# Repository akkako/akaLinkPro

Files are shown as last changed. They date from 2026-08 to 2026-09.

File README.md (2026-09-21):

# akaLinkPro

akaLinkPro 是一个基于 HPM5300 的高性能 CMSIS-DAP 调试器。

- 主固件：`firmware/application_5301`
- DFU/MSC Bootloader：`firmware/bootloader_dfu`
- 配置上位机（WebHID）：`docs/index.html`

构建 / 烧录 / 调试说明见 `.opencode/skills/akalinkpro-firmware/SKILL.md`。

## License

本项目采用 **Apache License 2.0** 许可，详见根目录 [`LICENSE`](LICENSE)。

```
Copyright (c) 2026 akaInstruments

Licensed under the Apache License, Version 2.0 (the "License");
you may not use this file except in compliance with the License.
You may obtain a copy of the License at

    http://www.apache.org/licenses/LICENSE-2.0
```

## 第三方组件

本项目在源码与构建中使用/参考了以下第三方组件，其版权归各自作者所有，
并按其各自的许可证分发（这些组件的原始许可证声明请见对应文件/目录）：

| 组件 | 用途 | 许可证 |
| --- | --- | --- |
| [HPMicro HPM SDK](https://github.com/hpmicro/hpm_sdk) | HPM5301 SoC/驱动/启动/链接脚本 | BSD-3-Clause |
| [ARM CMSIS-DAP](https://github.com/ARM-software/CMSIS-DAP) | CMSIS-DAP 命令引擎（`src/dap/`） | Apache-2.0 |
| [CherryUSB](https://github.com/cherry-embedded/CherryUSB) | USB 设备协议栈 | Apache-2.0 |
| [CherryRB](https://github.com/cherry-embedded/CherryRB) | 无锁环形缓冲区 | Apache-2.0 |
| [EasyFlash](https://github.com/armink/EasyFlash) | 参数持久化（`src/easyflash/`） | MIT |

> 若再分发二进制，请一并保留上述组件的版权与许可证声明。

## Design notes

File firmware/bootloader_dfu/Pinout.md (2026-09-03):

# akaLink Pro Pinout define

| Pin name | IO name | alt function | description | Init state |
| --- | --- | --- | --- | --- |
| ISP_TX | PA00 | UART0.TXD | ISP and debug print serial port | |
| ISP_RX | PA01 | UART0.RXD | ISP and debug print serial port | |
| BOOT0 | PA02 | None | Strapping pin | |
| BOOT1 | PA03 | None | Strapping pin | |
| DBG_JTDO | PA04 | JTAG | Debug port | |
| DBG_JTDI | PA05 | JTAG | Debug port | |
| DBG_JTCK | PA06 | JTAG | Debug port | |
| DBG_JTMS | PA07 | JTAG | Debug port | |
| JTDI_TXD | PA08 | UART2.TXD | VCOM port | |
| JTDO_RXD | PA09 | UART2.RXD | VCOM port | |
| DFU_PIN  | PA10 | GPIO0 Input | DFU mode entry detect | Pull-down GPIO0 Input |
| USB_D+ | PA24 | USB | USB communication pin | |
| USB_D- | PA25 | USB | USB communication pin | |
| nRESET | PA26 | GPIO0 Output | | GPIO0 Output Low |
| JTCK | PA27 | FGPIO Output | | |
| JTMS_IN  | PA28 | FGPIO Input  | | |
| JTMS_OUT | PA29 | FGPIO Output | | |
| JTMS_DIR | PA30 | FGPIO Output | | |
| JTRST | PA31 | GPIO0 Output | | |
| SEL0 | PB08 | GPIO0 Input | Device hardware type detect | Pull-up GPIO0 Input |
| SEL1 | PB09 | GPIO0 Input | Device hardware type detect | Pull-up GPIO0 Input |
| ADC_VREF | PB10 | ADC0.IN2 | External Vref detect | |
| LED1 | PB11 | GPIO0 Output | | GPIO0 Output Low |
| LED2 | PB12 | GPIO0 Output | | GPIO0 Output Low |
| 5V_EN | PB13 | GPIO0 Output | | GPIO0 Output Low |
| AUX_RXD  | PB14 | UART3.RXD | Auxiliary COM port | |
| AUX_TXD  | PB15 | UART3.TXD | Auxiliary COM port | |
| Unused | PY00 | None | | GPIO0 Output Low |
| Unused | PY01 | None | | GPIO0 Output Low |

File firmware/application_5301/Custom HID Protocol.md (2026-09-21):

# Custom HID 通信协议

## HID 数据包

固定长度64字节

Byte[0x00] = Report ID
Byte[0x01] = Data Length（包括 Command type 和后面的数据长度）
Byte[0x02] = Command type
Byte[0x03-0x3F] = Command data（可选）

- 主机下发 request 使用 Report ID 0x01，设备回应 response 使用 Report ID 0x02。
- Data Length = Command type 字节数(1) + 后续有效数据字节数。

## 指令类型

1. 获取配置指令 0x01
   主机发送 request
   Byte[0x00] = 0x01 // Report ID
   Byte[0x01] = 0x01 // Data Length
   Byte[0x02] = 0x01 // Command type
   设备回应 response
   Byte[0x00] = 0x02 // Report ID
   Byte[0x01] = 0x07 // Data Length
   Byte[0x02] = 0x01 // Command type
   Byte[0x03] = 输出模式 0x00 - SWD + VCOM; 0x01 - SWD + JTAG
   Byte[0x04] = 5V输出模式 0x00 - Disable; 0x01 - Enable
   Byte[0x05] = 时钟加速模式 0x00 - Disable; 0x01 - Enable
   Byte[0x06] = LED1 显示模式 0x01 - 0x09（见配置说明）
   Byte[0x07] = LED2 显示模式 0x01 - 0x09（见配置说明）
   Byte[0x08] = 外部参考设定值 低八位（单位 mV）
   Byte[0x09] = 外部参考设定值 高八位（单位 mV，范围 1800 - 5000）
   设备回应代表成功

2. 设置配置指令 0x02
   主机发送 request
   Byte[0x00] = 0x01 // Report ID
   Byte[0x01] = 0x07 // Data Length
   Byte[0x02] = 0x02 // Command type
   Byte[0x03] = 输出模式 0x00 - SWD + VCOM; 0x01 - SWD + JTAG
   Byte[0x04] = 5V输出模式 0x00 - Disable; 0x01 - Enable
   Byte[0x05] = 时钟加速模式 0x00 - Disable; 0x01 - Enable
   Byte[0x06] = LED1 显示模式 0x01 - 0x09
   Byte[0x07] = LED2 显示模式 0x01 - 0x09
   Byte[0x08] = 外部参考设定值 低八位（单位 mV）
   Byte[0x09] = 外部参考设定值 高八位（单位 mV，范围 1800 - 5000）
   设备回应 response
   Byte[0x00] = 0x02 // Report ID
   Byte[0x01] = 0x01 // Data Length
   Byte[0x02] = 0x02 // Command type
   设备回应代表成功
   说明：本指令只写入内存并立即生效，掉电不保存；需要掉电保存请随后发送保存配置指令 0x04。
   越界的 LED 模式会被钳制为 0x09（常灭），越界的外部参考设定值会被钳制到 1800 - 5000。

3. 获取 Target 电压获取指令 0x03
   主机发送 request
   Byte[0x00] = 0x01 // Report ID
   Byte[0x01] = 0x01 // Data Length
   Byte[0x02] = 0x03 // Command type
   设备回应 response
   Byte[0x00] = 0x02 // Report ID
   Byte[0x01] = 0x03 // Data Length
   Byte[0x02] = 0x03 // Command type
   Byte[0x03] = 电压数据低八位
   Byte[0x04] = 电压数据高八位（电压单位为mV）
   设备回应代表成功
   说明：返回 PB10 分压点经 x2 还原后的外部参考电压（ADC 量程 3.3V）。

4. 保存当前配置设置指令 0x04
   主机发送 request
   Byte[0x00] = 0x01 // Report ID
   Byte[0x01] = 0x01 // Data Length
   Byte[0x02] = 0x04 // Command type
   设备回应 response
   Byte[0x00] = 0x02 // Report ID
   Byte[0x01] = 0x01 // Data Length
   Byte[0x02] = 0x04 // Command type
   设备回应代表成功
   说明：将当前配置写入 flash 持久化保存，见“配置持久化”章节。

5. 获取型号指令 0x10
   主机发送 request
   Byte[0x00] = 0x01 // Report ID
   Byte[0x01] = 0x01 // Data Length
   Byte[0x02] = 0x10 // Command type
   设备回应 response
   Byte[0x00] = 0x02 // Report ID
   Byte[0x01] = 0x13 // Data Length
   Byte[0x02] = 0x10 // Command type
   Byte[0x03] = 'a'
   Byte[0x04] = 'k'
   Byte[0x05] = 'a'
   Byte[0x06] = 'L'
   Byte[0x07] = 'i'
   Byte[0x08] = 'n'
   Byte[0x09] = 'k'
   Byte[0x0A] = ' '
   Byte[0x0B] = 'C'
   Byte[0x0C] = 'M'
   Byte[0x0D] = 'S'
   Byte[0x0E] = 'I'
   Byte[0x0F] = 'S'
   Byte[0x10] = '-'
   Byte[0x11] = 'D'
   Byte[0x12] = 'A'
   Byte[0x13] = 'P'
   Byte[0x14] = \0
   设备回应代表成功

6. 获取序列号指令 0x11
   主机发送 request
   Byte[0x00] = 0x01 // Report ID
   Byte[0x01] = 0x01 // Data Length
   Byte[0x02] = 0x11 // Command type
   设备回应 response
   Byte[0x00] = 0x02 // Report ID
   Byte[0x01] = 0x0E // Data Length
   Byte[0x02] = 0x11 // Command type
   Byte[0x03] = SN 第 1 位 ACSII
   Byte[0x04] = SN 第 2 位 ACSII
   Byte[0x05] = SN 第 3 位 ACSII
   Byte[0x06] = SN 第 4 位 ACSII
   Byte[0x07] = SN 第 5 位 ACSII
   Byte[0x08] = SN 第 6 位 ACSII
   Byte[0x09] = SN 第 7 位 ACSII
   Byte[0x0A] = SN 第 8 位 ACSII
   Byte[0x0B] = SN 第 9 位 ACSII
   Byte[0x0C] = SN 第 10 位 ACSII
   Byte[0x0D] = SN 第 11 位 ACSII
   Byte[0x0E] = SN 第 12 位 ACSII
   Byte[0x0F] = \0
   设备回应代表成功

7. 获取硬件版本号 0x12
   主机发送 request
   Byte[0x00] = 0x01 // Report ID
   Byte[0x01] = 0x01 // Data Length
   Byte[0x02] = 0x12 // Command type
   设备回应 response
   Byte[0x00] = 0x02 // Report ID
   Byte[0x01] = 0x06 // Data Length
   Byte[0x02] = 0x12 // Command type
   Byte[0x03] = HW 第 1 位 ACSII
   Byte[0x04] = HW 第 2 位 ACSII
   Byte[0x05] = HW 第 3 位 ACSII
   Byte[0x06] = HW 第 4 位 ACSII
   Byte[0x07] = \0
   设备回应代表成功

8. 获取固件版本号 0x13
   主机发送 request
   Byte[0x00] = 0x01 // Report ID
   Byte[0x01] = 0x01 // Data Length
   Byte[0x02] = 0x13 // Command type
   设备回应 response
   Byte[0x00] = 0x02 // Report ID
   Byte[0x01] = 0x06 // Data Length
   Byte[0x02] = 0x13 // Command type
   Byte[0x03] = FW 第 1 位 ACSII
   Byte[0x04] = FW 第 2 位 ACSII
   Byte[0x05] = FW 第 3 位 ACSII
   Byte[0x06] = FW 第 4 位 ACSII
   Byte[0x07] = \0
   设备回应代表成功

9. 获取Bootloader版本号 0x14
   主机发送 request
   Byte[0x00] = 0x01 // Report ID
   Byte[0x01] = 0x01 // Data Length
   Byte[0x02] = 0x14 // Command type
   设备回应 response
   Byte[0x00] = 0x02 // Report ID
   Byte[0x01] = 0x06 // Data Length
   Byte[0x02] = 0x14 // Command type
   Byte[0x03] = BL 第 1 位 ACSII
   Byte[0x04] = BL 第 2 位 ACSII
   Byte[0x05] = BL 第 3 位 ACSII
   Byte[0x06] = BL 第 4 位 ACSII
   Byte[0x07] = \0
   设备回应代表成功

10. 获取硬件生产日期指令 0x15
   主机发送 request
   Byte[0x00] = 0x01 // Report ID
   Byte[0x01] = 0x01 // Data Length
   Byte[0x02] = 0x15 // Command type
   设备回应 response
   Byte[0x00] = 0x02 // Report ID
   Byte[0x01] = 0x15 // Data Length
   Byte[0x02] = 0x15 // Command type
   Byte[0x03-0x15] = 日期字符串（19 字节，如 "2026-08-06"）
   Byte[0x16] = \0
   设备回应代表成功

11. 获取固件编译日期指令 0x16
   主机发送 request
   Byte[0x00] = 0x01 // Report ID
   Byte[0x01] = 0x01 // Data Length
   Byte[0x02] = 0x16 // Command type
   设备回应 response
   Byte[0x00] = 0x02 // Report ID
   Byte[0x01] = 0x15 // Data Length
   Byte[0x02] = 0x16 // Command type
   Byte[0x03-0x15] = 日期字符串（19 字节）
   Byte[0x16] = \0
   设备回应代表成功

12. 获取Bootloader编译日期指令 0x17
   主机发送 request
   Byte[0x00] = 0x01 // Report ID
   Byte[0x01] = 0x01 // Data Length
   Byte[0x02] = 0x17 // Command type
   设备回应 response
   Byte[0x00] = 0x02 // Report ID
   Byte[0x01] = 0x15 // Data Length
   Byte[0x02] = 0x17 // Command type
   Byte[0x03-0x15] = 日期字符串（19 字节）
   Byte[0x16] = \0
   设备回应代表成功

13. 设备复位指令 0xFE
   主机发送 request
   Byte[0x00] = 0x01 // Report ID
   Byte[0x01] = 0x01 // Data Length
   Byte[0x02] = 0xFE // Command type
   设备复位，不会回复，此时连接断开

14. 进入DFU模式设置指令 0xFF
   主机发送 request
   Byte[0x00] = 0x01 // Report ID
   Byte[0x01] = 0x01 // Data Length
   Byte[0x02] = 0xFF // Command type
   设备复位进入DFU模式，不会回复，此时连接断开

## 配置说明

1. 输出模式
0x00 - SWD + VCOM 此时 JTAG 功能不可用，TDI 和 TDO 用于 UART
0x01 - SWD + JTAG 此时 VCOM 功能不可用，TDI 和 TDO 用于 JTAG

2. 5V输出模式
0x00 - 关闭 5V 对外输出
0x01 - 开启 5V 对外输出，可以用于为外接隔离器模块或目标板供电
注意：该引脚同时给板载电平转换供电，关闭后 JTAG/SWD 电平转换可能无法工作；出厂默认开启。

3. 时钟加速模式
0x00 - 关闭时钟加速模式，此时 DAP_SWJ_Clock 指令将按照设定频率向下取整设置 SWD 和 JTAG 输出频率，适用于 openocd 等上位机
0x01 - 开启时钟加速模式，此时 DAP_SWJ_Clock 指令将按照设定频率x10向下取整设置 SWD 和 JTAG 输出频率，适用于 Keil MDK 上位机

4. LED 显示模式（LED1 = PB11 蓝色，LED2 = PB12 黄色，高电平点亮）
可分别为两个 LED 配置 0x01 - 0x09 中任意一种模式，两个 LED 可相同也可不同：

0x01 - DAP RUNNING 状态：RUNNING=1 则亮，=0 则灭
0x02 - DAP CONNECT 状态：CONNECT=1 则亮，=0 则灭
0x03 - DAP 状态：RUNNING 与 CONNECT 任一为 1 则以 5Hz（200ms 周期，亮/灭各 100ms）闪烁，两者都为 0 则常亮
0x04 - 调试器电源状态：上电常亮
0x05 - 外部参考电源状态：ADC 检测到外部参考电压高于设定值的 90% 时点亮，低于 85% 时熄灭（5% 滞回）
0x06 - CDC 串口 TX 状态（调试器 UART 向外发数据）：有数据发送时点亮，最低点亮 50ms，持续发送则常亮
0x07 - CDC 串口 RX 状态（调试器 UART 接收数据）：有数据接收时点亮，最低点亮 50ms，持续接收则常亮
0x08 - CDC 串口 TX 或 RX 状态：TX 或 RX 任一触发，逻辑同上
0x09 - 常灭

出厂默认：LED1 = 0x04，LED2 = 0x05。

5. 外部参考电压设定值（单位 mV，范围 1800 - 5000）
用于 LED 显示模式 0x05 的判定阈值，对应经 x2 还原后的外部参考电压。出厂默认 3300mV。

## 配置持久化

- 设置配置指令（0x02）只修改内存中的配置并立即生效，掉电丢失。
- 保存配置指令（0x04）通过 **EasyFlash（ENV, NG 模式）** 写入 QSPI NOR flash，
  具备磨损平衡与掉电保护。
- 存储位置：APP 固件区尾部保留的两个 4K 扇区（`0x800FE000` 与 `0x800FF000`），
  不占用 Bootloader 区（`0x80000000` - `0x8001FFFF`）。
- ENV key 为 `"cfg"`，value 为整个 `api_param_t`；上电自动加载，校验失败则写回出厂默认。
- 常规 APP 升级（J-Link 或 dfu-util）不会覆盖该区域。
- 详见 `Flash_Memory_Map.md` 与 `Firmware_Integrity_Plan.md`。

## 固件元数据（版本 / CRC）

- 版本、编译时间、描述、硬件版本等由构建后 `firmware/tools/pack.py` 注入：
  - **APP**：`0x80020000` 起 256 B 头（签名 + 长度 + CRC32 + 版本 + 编译时间 + 描述），代码入口 `0x80020100`；
  - **Bootloader**：`0x8001F000` 起 256 B 信息块（版本 + 编译时间 + 硬件版本 + 生产日期）。
- 版本单一来源：`firmware/version.json`；编译时间取打包时刻。
- Bootloader 启动时校验 APP 头（签名 + 长度 + CRC32），失败则停留在 DFU 模式。
- 指令 `0x12`–`0x17` 即从上述固定地址读取返回。

## WebUI 配置界面

点击连接按钮尝试连接 HID 设备
弹出 HID 设备选择框，选择 akaLink CMSIS-DAP 设备
进行连接，如果连接失败显示错误提示信息
连接成功，读取型号，序列号，配置信息，并将数据显示在页面上
此时可以修改配置，修改完配置不立即写入
点击保存配置按钮，将配置写入并保存
点击复位按钮，进行复位操作
点击进入DFU模式按钮，进入DFU模式

需要实时监测 HID 设备的连接状态，如果丢失连接要及时响应，清除显示的数据
在未连接状态下，只有连接按钮可用，其他按钮不可用，配置项目不可选

每个配置项和按键，当鼠标指上去的时候需要有提示信息

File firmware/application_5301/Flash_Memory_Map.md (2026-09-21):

# akaLink Pro Flash 存储区分布

适用芯片：**HPM5301**，外挂 **1 MB QSPI NOR**，XIP 基址 `0x80000000`。
NOR 扇区（sector）大小：**4 KB (0x1000)**，共 256 个扇区（扇区号 0 – 255）。

> 所有地址均为 CPU 视角的 flash 映射地址（XIP）。写入/擦除通过 ROM API
> (`rom_xpi_nor_*`) 完成，偏移量为「映射地址 − 0x80000000」。

## 1. 总体分布

| 区域 | 起始地址 | 结束地址 | 大小 | 扇区号 | 说明 |
| --- | --- | --- | --- | --- | --- |
| Bootloader 代码 | `0x80000000` | `0x8001EFFF` | < 124 KB | 0 – 30 | DFU 引导程序（实际 ~40 KB） |
| Bootloader 信息块 | `0x8001F000` | `0x8001F0FF` | 256 B | 31 | 版本/编译时间/硬件版本/生产日期 |
| APP 头 | `0x80020000` | `0x800200FF` | 256 B | 32 | DFU 签名 + 长度 + CRC32 + 版本/时间/描述 |
| APP 代码 | `0x80020100` | `0x800FDFFF` | ~895 KB | 32 – 253 | 应用程序链接区，入口 `0x80020100` |
| EasyFlash ENV 区 | `0x800FE000` | `0x800FFFFF` | 8 KB | 254 – 255 | 配置持久化（见 §4） |

- APP 头首 4 字节为 DFU 签名 `0x48504D21`（"HPM!"），代码入口 `0x80020100`。
- Bootloader 校验通过后跳转到 `0x80020100`。
- 元数据由构建后 `firmware/tools/pack.py` 注入，详见 §3.2 / §4.5。

## 2. Bootloader 区（`0x80000000` – `0x8001FFFF`）

| 地址 | 内容 | 说明 |
| --- | --- | --- |
| `0x80000400` | `nor_cfg_option` | QSPI NOR 配置字（Rom 引导用） |
| `0x80001000` | `boot_header` | HPM 启动头 |
| `0x80003000` | `.start` / 代码 | Bootloader 可执行代码 |
| `0x8001FFFC` | 保留 | 区尾，下一个区域为 APP |

## 3. APP 固件区（`0x80020000` – `0x800FDFFF`）

| 地址 | 内容 | 说明 |
| --- | --- | --- |
| `0x80020000`–`0x800200FF` | **APP 头** | 见 §3.1；由 `pack.py` 注入 |
| `0x80020100` | 代码入口 `_start` | 实际占用约 80 KB（随版本变化） |
| 区尾 `0x800FDFFF` | APP 区上界（含） | 其后为 8 KB EasyFlash 区 |

APP 区使用**自定义链接脚本** `linker/flash_dfu_app.ld`（经 `CUSTOM_GCC_LINKER_FILE` 指定），
在 `.dfu_signature` 之后 `. = ALIGN(0x100)` 预留 APP 头，使入口落到 `0x80020100`。
区大小仍为 `APP_LENGTH = _flash_size − _dfu_bl_length = 0xFE000 − 0x20000 = 0xDE000`。

### 3.1 APP 头结构（256 B @ `0x80020000`）

| 偏移 | 长度 | 字段 | 来源 |
| --- | --- | --- | --- |
| `0x00` | 4 | DFU 签名 `0x48504D21` | 链接器（保持） |
| `0x04` | 4 | 代码长度 `app_code_len` | `pack.py` |
| `0x08` | 4 | 代码 CRC32（种子 `0x0D000721`） | `pack.py` |
| `0x0C` | 4 | 头格式版本 = 1 | `pack.py` |
| `0x10` | 8 | 固件版本串 | `version.json: app_fw_ver` |
| `0x18` | 20 | 固件编译时间 `YYYY/MM/DD HH:MM:SS` | 打包时刻 |
| `0x2C` | 24 | 固件描述 | `version.json: app_desc` |
| `0x44` | 0xBC | 保留 | — |

## 3.2 Bootloader 信息块（256 B @ `0x8001F000`）

| 偏移 | 长度 | 字段 | 来源 |
| --- | --- | --- | --- |
| `0x00` | 4 | magic `"BLI1"` (`0x31494C42`) | `pack.py` |
| `0x04` | 4 | Bootloader 代码长度 | `pack.py` |
| `0x08` | 4 | Bootloader CRC32（预留，未校验） | — |
| `0x0C` | 4 | 格式版本 = 1 | `pack.py` |
| `0x10` | 8 | Bootloader 版本串 | `version.json: bl_ver` |
| `0x18` | 20 | Bootloader 编译时间 | 打包时刻 |
| `0x2C` | 8 | 硬件版本串 | `version.json: hw_ver` |
| `0x34` | 20 | 硬件生产日期 | `version.json: hw_prod_date` |

### 3.3 版本信息源

统一配置于 `firmware/version.json`（`app_fw_ver` / `app_desc` / `bl_ver` / `hw_ver` / `hw_prod_date`），
由 app 与 bootloader 的 `pack.py`（`firmware/tools/pack.py`）在构建后写入；编译时间取打包时刻。

## 4. 参数存储区（`0x800FE000` – `0x800FFFFF`，EasyFlash）

由 **EasyFlash（ENV, NG 模式）** 管理的持久化区，占用 2 个 4 KB 扇区（8 KB），
自带磨损平衡与掉电保护，不再使用早期的双槽 ping-pong 自定义格式。

| 区域 | 地址范围 | 扇区号 | 大小 | 说明 |
| --- | --- | --- | --- | --- |
| EasyFlash ENV 区 | `0x800FE000` – `0x800FFFFF` | 254 – 255 | 8 KB | `ENV_AREA_SIZE`，`EF_START_ADDR` |

- 逻辑：ENV key `"cfg"` 保存整个 `api_param_t` blob（`ef_get_env_blob`/`ef_set_env_blob`）。
- 物理：每个扇区头 magic `EF40`；每个 ENV 节点头 magic `KV40` + 长度 + CRC32 + 状态位；
  2 个扇区间自动 GC / 磨损平衡，一个扇区通常留作 GC 空扇区。
- 出厂默认：由 `api_param.c` 的 `g_param_default` 提供（`ef_port.c` 的 `default_env_set`），
  首次上电 / 扇区无效 / `EF_ENV_VER_NUM` 变化时写入。
  默认值：`output_mode=0, usb5v=1, clock_accel=0, led1=4, led2=5, vref=3300`。

分层实现：

| 层 | 文件 | 职责 |
| --- | --- | --- |
| 硬件驱动 (`drv`) | `src/drv/drv_flash.c/.h` | 封装 ROM API：`drv_flash_init/read/erase/write`，处理字节对齐与 Cache |
| 存储库端口 | `src/easyflash/port/ef_port.c` | 把 EasyFlash 的 `ef_port_read/erase/write/env_lock` 及默认 ENV 接到 `drv_flash` |
| 存储库 | `src/easyflash/src/*` | EasyFlash 本体（ENV/GC/CRC） |
| 应用 | `src/api/api_param.c` | 通过 `ef_get_env_blob`/`ef_set_env_blob("cfg")` 存取配置 |

> 驱动/存储库不感知业务字段，应用层只面对 key/value，换存储介质只需改 `drv` 层。

## 5. 相关代码 / 链接约束（改尾部保留区时必须同步）

| 位置 | 约束 | 当前值 |
| --- | --- | --- |
| `application_5301/CMakeLists.txt` | APP 链接 `_flash_size`（决定 APP 区上界） | `0xFE000`（= 1 MB − 8 KB） |
| `application_5301/CMakeLists.txt` | Bootloader 预留 `_dfu_bl_length` | `0x20000` |
| `application_5301/CMakeLists.txt` | APP 自定义链接脚本 `CUSTOM_GCC_LINKER_FILE` | `linker/flash_dfu_app.ld` |
| `application_5301/CMakeLists.txt` | APP POST_BUILD 打包（写入 APP 头） | `tools/pack.py app` |
| `bootloader_dfu/CMakeLists.txt` | Bootloader POST_BUILD 打包（写入信息块） | `tools/pack.py boot` |
| `firmware/version.json` | 版本/描述/硬件信息唯一来源 | 见 §3.3 |
| `application_5301/boards/akaLinkPro/board.h` | 尾部保留大小 `BOARD_PARAM_RESERVED_SIZE` | `0x2000`（8 KB） |
| `application_5301/src/easyflash/inc/ef_cfg.h` | `EF_START_ADDR` / `ENV_AREA_SIZE`（= 尾部保留区） | 由 `BOARD_*` 推出 |
| `bootloader_dfu/boards/akaLinkPro/board.h` | `BOARD_DFU_WRITABLE_SIZE` | `BOARD_FLASH_SIZE − 0x2000` |
| `bootloader_dfu/src/dfu_flash_port.c` | DFU 擦除/写入/读取上界 | `< 0x800FE000` |
| `bootloader_dfu/src/dfu_desc.c` | DfuSe 描述的可写区大小 | 扣除 8 KB |

EasyFlash ENV 区地址：
`EF_START_ADDR = 0x80000000 + BOARD_FLASH_SIZE − BOARD_PARAM_RESERVED_SIZE`
`ENV_AREA_SIZE = BOARD_PARAM_RESERVED_SIZE`（= 2 × `EF_ERASE_MIN_SIZE` = 2 × 4 KB）

## 6. 新增自定义数据区的方法

在 **flash 顶端**从 EasyFlash 区继续向下预留（保持 Bootloader 区不动），并同步缩小 APP 区。

### 6.1 示例：新增 2 个扇区（8 KB）自定义数据区

把 APP 区上界从 `0x800FE000` 下调到 `0x800FC000`，自定义区放 `0x800FC000` – `0x800FDFFF`。调整后布局：

| 区域 | 地址范围 | 扇区号 | 大小 |
| --- | --- | --- | --- |
| APP 固件 | `0x80020000` – `0x800FBFFF` | 32 – 251 | 880 KB |
| 自定义数据区（示例） | `0x800FC000` – `0x800FDFFF` | 252 – 253 | 8 KB |
| EasyFlash ENV 区 | `0x800FE000` – `0x800FFFFF` | 254 – 255 | 8 KB |

此时尾部总保留 `TAIL = 4 × 0x1000 = 0x4000`：APP `_flash_size = 0x100000 − 0x4000 = 0xFC000`。

### 6.2 修改清单（模板）

设新增数据区共 `K` 个扇区，尾部总保留 `TAIL = (2 + K) × 0x1000` 字节：

| 文件 | 修改 |
| --- | --- |
| `application_5301/CMakeLists.txt` | `_flash_size = 0x100000 − TAIL` |
| `application_5301/boards/akaLinkPro/board.h` | `BOARD_PARAM_RESERVED_SIZE` → 改用实际尾部总保留大小（或新增 `BOARD_TAIL_RESERVED_SIZE`） |
| `application_5301/src/easyflash/inc/ef_cfg.h` | `EF_START_ADDR`/`ENV_AREA_SIZE` 按新的 EasyFlash 区重算 |
| `bootloader_dfu/boards/akaLinkPro/board.h` | `BOARD_DFU_WRITABLE_SIZE = BOARD_FLASH_SIZE − TAIL` |
| `bootloader_dfu/src/dfu_flash_port.c` | 无需改（引用 `BOARD_DFU_WRITABLE_SIZE`），确保不越界 |
| `bootloader_dfu/src/dfu_desc.c` | DfuSe 描述扣除 `TAIL` |

自定义数据区建议（两种方式）：
- **使用 EasyFlash**：为每个数据区分配独立的 ENV key（如 `"factory"`、`"calib"`），
  由 EasyFlash 统一做 GC / 磨损平衡；地址只需在 `ef_cfg.h` 调整 ENV 区范围与 `default_env_set`。
- **裸 drv_flash**：直接调用 `drv_flash_read/erase/write(addr, buf, size)`（绝对地址，字节粒度），
  自行在区首放 `magic + version + CRC32`，写前先 `drv_flash_erase` 整个扇区。
- 每个独立数据区至少占 1 个 4 KB 扇区（擦除最小单位）。
- 地址计算：`区起始 = 0x80100000 − TAIL + 本区在尾部内的偏移`。

## 7. 快速校验命令（J-Link）

```
device HPM5301xEGx
si JTAG
jtagconf -1 -1
speed 4000
connect
mem8  0x80020000,64     // APP 头：21 4D 50 48 + len + CRC32 + "0.1" + 时间 + 描述
mem8  0x80020100,8      // APP 入口代码（_start）
mem8  0x8001F000,64     // Bootloader 信息块："BLI1" + "1.0" + 时间 + "A.0" + 生产日期
mem8  0x800FE000,16     // EasyFlash 扇区头，含 "EF40" (45 46 34 30)
mem8  0x800FE010,16     // ENV 节点头 "KV40" (4B 56 34 30) + key "cfg"
mem8  0x800FF000,16     // 第二个 ENV 扇区（GC 备用，通常为空）
exit
```

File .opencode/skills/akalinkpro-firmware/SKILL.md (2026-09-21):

---
name: akalinkpro-firmware
description: akaLinkPro (HPM5301 CMSIS-DAP) firmware build, flash and debug guide. Use when building, flashing (J-Link/JTAG or dfu-util), debugging (VSCode GDB / J-Link GDB Server), or editing files under firmware/application_5301 and firmware/bootloader_dfu in this repo.
---

# akaLinkPro 固件构建 / 烧录 / 调试

本仓库是 **HPM5301** 上的 CMSIS-DAP 调试器（akaLinkPro）。
- 主固件：`firmware/application_5301`（`akaLinkPro_App`）
- DFU Bootloader：`firmware/bootloader_dfu`（`akaLinkPro_Boot`）
- `firmware/application_5331` 是另一芯片变体，非本流程重点。

调试探针：**J-Link V11**，串口 `50120677`，**只能走 JTAG**。

---

## 0. 其他 skill 索引

除了阅读本 skill 外，还应该阅读以下skill：

```
	jlink/SKILL.md
```

## 1. 目录结构

```
firmware/
  version.json                      版本/描述/硬件信息唯一来源（pack 读取）
  tools/pack.py                     构建后注入 APP 头(长度/CRC32/版本/时间/描述) 与 BL 信息块
  application_5301/                 主固件 (CMSIS-DAP)
    CMakeLists.txt                  自定义链接脚本 linker/flash_dfu_app.ld；POST_BUILD 调用 pack.py
    linker/flash_dfu_app.ld         预留 256B APP 头，入口 0x80020100（CUSTOM_GCC_LINKER_FILE）
    build_dfu.bat                   构建到 ./build_dfu（不调用 dfu-util）
    program.bat                     对 build_dfu 产物执行 dfu-util 烧录（用 _pack.bin）
    flash_jlink.bat                 build_dfu + JLink 烧录 APP（用 _pack.hex）
    gdb_server.bat                  启动 JLinkGDBServerCL（VSCode 调试用）
    Flash_Memory_Map.md             Flash 布局（含元数据/ EasyFlash）
    Firmware_Integrity_Plan.md      完整性校验+版本嵌入方案与自检
    Custom HID Protocol.md          HID 协议（配置/元数据）
    boards/akaLinkPro/              board.c/h, clock.c/h, pinmux.c/h, akaLinkPro.yaml
    src/  main.c, usb/, dap/, api/, led/, drv/, easyflash/, dfu/
  bootloader_dfu/                   DFU Bootloader
    CMakeLists.txt                  链接 flash_xip.ld，128K flash；POST_BUILD 调用 pack.py
    build.bat / build_xip.bat       ./build / ./build_xip（JLink 流程）
    flash_jlink.bat                 build_xip + JLink 烧录 bootloader（用 _pack.hex）
    src/  main.c, dfu_desc.c, hpm_dfu_trigger.c, boot_port_board_hpm.c, dfu_flash_port.c,
          vfat.c/.h（虚拟 FAT16 U 盘）, msc_if.c（MSC 回调）
    Bootloader_USB_Upgrade_Plan.md  U 盘升级方案
```

构建产物目录 `build` / `build_xip` / `build_dfu` 均已在 `.gitignore` 中忽略。
每次构建后生成 **打包镜像** `*_pack.hex` / `*_pack.bin`（含元数据），烧录请用打包镜像。

---

## 2. 内存布局与关键地址

HPM5301，外挂 1MB QSPI NOR，XIP 基址 `0x80000000`。

| 区域 | 地址 | 链接脚本 | 说明 |
| --- | --- | --- | --- |
| Bootloader 代码 | `0x80000000 - 0x8001EFFF` | `flash_xip.ld` | 含 `nor_cfg_option`@0x400、`boot_header`@0x1000、`.start`@0x3000 |
| Bootloader 信息块 | `0x8001F000 - 0x8001F0FF` (256B) | — | `pack.py` 写入：BL 版本/编译时间/硬件版本/生产日期 |
| APP 头 | `0x80020000 - 0x800200FF` (256B) | `flash_dfu_app.ld` | 签名 + 长度 + CRC32 + 版本/编译时间/描述 |
| APP 代码 | `0x80020100 - 0x800FDFFF` | `flash_dfu_app.ld` | **入口 `0x80020100`** |
| EasyFlash ENV | `0x800FE000 - 0x800FFFFF` (8K) | — | 配置持久化（2×4K 扇区，EasyFlash） |
| ILM | `0x00000000` (128K) | — | 向量表 / `.fast` |
| DLM | `0x00080300` | — | data / bss / heap / stack |
| AHB_SRAM | `0xF0400000` (32K) | — | `.ahb_sram` |

- DFU 签名：`0x80020000` 必须为 `0x48504D21`（`"HPM!"`，`BOARD_DFU_SIGNATURE`）。
- Bootloader 在 `hpm_dfu_check_bootloader_request()` 中校验 **签名 + 长度 + CRC32**（`app_image_valid()`），
  成功跳到 `0x80020100`，**失败则停留 DFU 模式**。
- **APP 用自定义链接脚本** `application_5301/linker/flash_dfu_app.ld`（经 `CUSTOM_GCC_LINKER_FILE`），
  在 `.dfu_signature` 后 `. = ALIGN(0x100)` 预留 APP 头；APP 不再直接链接到 `flash_dfu.ld`。
- 头/信息块由 `firmware/tools/pack.py` 注入，版本源 `firmware/version.json`；编译时间取打包时刻。
- 详见 `application_5301/Flash_Memory_Map.md`、`application_5301/Firmware_Integrity_Plan.md`。
- DFU 引导程序自身只能 J-Link 烧录（不升级自身）。

---

## 3. 工具链与依赖（当前机器固定路径）

| 用途 | 路径 |
| --- | --- |
| HPM SDK | `D:\_tools\hpm_sdk\hpm_sdk` |
| RISC-V GCC / GDB | `D:\_tools\hpm_sdk\toolchains\rv32imac_zicsr_zifencei_multilib_b_ext-win\bin` |
| python / cmake / ninja | `D:\_tools\hpm_sdk\tools\{python3,cmake\bin,ninja}` |
| J-Link | `C:\Program Files\SEGGER\JLink\JLink.exe`，`JLinkGDBServerCL.exe` |
| dfu-util | 已在 PATH 中 |

GDB：`...\toolchains\...\bin\riscv32-unknown-elf-gdb.exe`

环境变量（各 `build*.bat` 已内置）：
`HPM_SDK_BASE`、`GNURISCV_TOOLCHAIN_PATH`、`HPM_SDK_TOOLCHAIN_VARIANT=gcc`、`BOARD=akaLinkPro`、`HPM_BUILD_TYPE`。

---

## 4. 构建

```bat
:: Bootloader (flash_xip @0x80000000) -> build_xip\
firmware\bootloader_dfu\build_xip.bat

:: App (flash_dfu @0x80020000) -> build_dfu\   (生成 .hex/.bin 与打包 img)
firmware\application_5301\build_dfu.bat
```

构建后处理：两个工程都会在链接后调用 `firmware/tools/pack.py` 生成**打包镜像**：
- App：`build_dfu\output\akaLinkPro_App_pack.bin`（dfu-util）/ `_pack.hex`（J-Link）
- Boot：`build_xip\output\akaLinkPro_Boot_pack.hex`（含 `0x8001F000` 信息块）

其它入口：
- `bootloader_dfu\build.bat`（`./build`）
- `application_5301\build_dfu.bat` + `program.bat`（构建后用 dfu-util 烧录 `_pack.bin`）

---

## 5. 烧录

### 5.1 J-Link 一键烧录（推荐）

```bat
:: 1) 先烧 bootloader（保留 0x80020000 处已有 APP）
firmware\bootloader_dfu\flash_jlink.bat

:: 2) 再烧 APP（只写 0x80020000 起的扇区，保留 bootloader）
firmware\application_5301\flash_jlink.bat
```

两个脚本都会：构建 -> 生成临时 `.jlink` 命令 -> 调用 `JLink.exe -NoGui 1 -ExitOnError 1` -> reset & go。
脚本内 `loadfile` 指向**打包镜像**（`*_pack.hex`）：APP 头 / Bootloader 信息块已包含其中；
烧未打包的 `.hex` 会因缺少元数据导致 Bootloader 校验失败而停留在 DFU。

J-Link 命令模板（直接改 `flash_jlink.bat` 时遵循）：

```
device HPM5301xEGx
si JTAG
jtagconf -1 -1
speed 4000
connect
Sleep 200
loadfile "<绝对路径.hex>"
Sleep 200
r
Sleep 300
go
Sleep 200
Exit
```

### 5.2 DFU 烧录

```bat
firmware\application_5301\build_dfu.bat   :: 先构建到 build_dfu\
firmware\application_5301\program.bat     :: 再 dfu-util 下载
:: program.bat 等价于:
:: dfu-util -a 0 -E 1 -s 0x80020000:leave -D build_dfu\output\akaLinkPro_App_pack.bin
```

APP 自带 DFU runtime 接口，`dfu-util` 会先发 `DFU_DETACH` 触发重启进入 bootloader，再传输。
**必须用 `_pack.bin`**（含 256B APP 头 + CRC32）；传输完成后 Bootloader 会校验并跳转。
Bootloader 自身不能用 DFU 升级（仅 J-Link）。

---

## 6. 调试

### 6.1 VSCode

打开 `firmware/application_5301` 作为工作区，选 **"Debug App (J-Link + GDB)"**（F5）。
`preLaunchTask` 会先执行 `build_dfu.bat`，再后台启动 `gdb_server.bat`，
cppdbg 通过 `localhost:2331` 连接，执行 `monitor reset -> load -> monitor reset`，
然后在 `main` 停下。

- `tasks.json` 用 `Waiting for GDB connection...` 作为后台任务就绪标志。
- `launch.json` 的 `program` 指向 `build_dfu/output/akaLinkPro_App.elf`。
- 调试 APP 时 bootloader 必须在 flash 中（它负责跳转到 APP）。

### 6.2 手动 GDB（命令行）

```bat
:: 终端 1：启动 GDB Server
"C:\Program Files\SEGGER\JLink\JLinkGDBServerCL.exe" ^
  -device HPM5301xEGx -if JTAG -speed 4000 -port 2331 -nogui -singlerun
```

```bat
:: 终端 2
"D:\_tools\hpm_sdk\toolchains\rv32imac_zicsr_zifencei_multilib_b_ext-win\bin\riscv32-unknown-elf-gdb.exe" ^
  firmware\application_5301\build_dfu\output\akaLinkPro_App.elf
```

```
(gdb) target extended-remote localhost:2331
(gdb) monitor reset
(gdb) load
(gdb) monitor reset
(gdb) break main
(gdb) continue
```

---

## 7. 验证设备状态

APP 运行时的 USB 描述符：`VID_0D28 & PID_0204`，接口 MI_00=CMSIS-DAP、MI_01=CDC(COM)、MI_03=HID、MI_04=WebUSB、MI_05=DFU Runtime。
Bootloader 模式：`VID_0D28 & PID_0207`（**复合设备 DFU + MSC**），MI_00=DFU（WinUSB，支持 dfu-util）、MI_01=MSC（U 盘）。
- 说明：0x0205 是旧 DFU-only PID，0x0206 在开发期被 Windows 缓存了旧 OS 描述符，故最终复合 PID 用 **0x0207**。
- WinUSB 由 **MS OS 2.0 描述符（WCID）** 自动安装到 DFU 接口，`dfu-util` 无需再手动绑驱动。

```powershell
Get-PnpDevice -PresentOnly | Where-Object { $_.InstanceId -match 'VID_0D28' } |
  Select-Object Status,Class,FriendlyName,InstanceId | Format-Table -AutoSize
```

读回 flash（确认已写入）：

```
device HPM5301xEGx
si JTAG
jtagconf -1 -1
speed 4000
connect
mem8 0x80020000 64     // APP 头：21 4D 50 48 + 长度 + CRC32 + 版本 + 时间 + 描述
mem8 0x80020100 8      // APP 入口代码（_start）
mem8 0x8001F000 64     // Bootloader 信息块："BLI1" + BL 版本 + 时间 + 硬件版本 + 生产日期
mem8 0x800FE000 16     // EasyFlash 扇区头，含 "EF40" (45 46 34 30)
Exit
```

---

## 7.1 Bootloader U 盘升级（MSC + 虚拟 FAT）

Bootloader 进入 DFU/升级模式时同时枚举一个 **MSC U 盘**（128MB FAT16，卷标 `AKALINKPRO`），
由 `bootloader_dfu/src/vfat.c` 提供（RAM 元数据 + APP flash 数据区，实际可写上限 = APP 区 `0x80020000..0x800FE000`，**不会碰尾部 EasyFlash**）：

| 文件 | 内容 |
| --- | --- |
| `INFO.TXT` | SN(OTP UID) / HWVER / BLVER / FWVER / DESC / CRC 状态 |
| `AKALINK.URL` | Internet Shortcut → `https://akkako.github.io/akaLinkPro/` |
| `AKALINK.HTM` | 同 URL 的 HTML meta 跳转（跨平台） |

- **拖拽升级**：把打包镜像改名（任意 `*.BIN`，如 `FIRMWARE.BIN`）拖入 U 盘 → 数据按 FAT 链写入
  APP 区 → 写满后延时 1s 复位 → Bootloader 校验（签名+长度+CRC32）通过则运行 APP，失败继续留在 U 盘。
- **镜像必须是打包镜像** `akaLinkPro_App_pack.bin`（含 256B 头），与 J-Link/dfu-util 一致。
- 只写属于该 `*.BIN` 的簇（会跳过 Windows 自动创建的 `System Volume Information`）。
- 进入升级模式：APP 的 `CMD_ENTER_DFU(0xFF)`、按住 boot 键、或 APP 校验失败时自动停留。
- 相关文档：`bootloader_dfu/Bootloader_USB_Upgrade_Plan.md`。

---

## 8. 5V 供电与 UART2 ↔ CDC 串口桥

### 5V 输出
- **PB13**（`POWER_5V_EN_PIN`）默认配置为 GPIO 输出**高电平**，给电平转换供电。
- 实现在 `boards/akaLinkPro/pinmux.c` 的 `init_power_pins()`（由 `board_init_gpio_pins()` 调用），
  可用 `board_set_5v_output(0/1)` 关闭/开启。

### UART2 复用规则（关键）
PA08 = JTDI/UART2_TXD，PA09 = JTDO/UART2_RXD，同一对引脚在两种功能间切换：

| DAP 状态 | PA08/PA09 | CDC COM 口 |
| --- | --- | --- |
| 未连接 / 空闲 / SWD 模式 | UART2 | 可用 |
| JTAG 模式 | FGPIO (TDI/TDO) | 保留但无数据 |

- 挂接点在 `src/dap/DAP_config.h`：`PORT_SWD_SETUP()`/`PORT_OFF()` 调 `uartx_enter_com_mode()`，
  `PORT_JTAG_SETUP()` 调 `uartx_enter_jtag_mode()`。
- `uartx_enter_jtag_mode()` **必须把 PA08/PA09 的 `FUNC_CTL` 清 0**，否则 UART2 仍占用引脚、JTAG 失效。
- 数据通路：USB CDC OUT → `g_usbrx` → UART2 TX（DMA）；UART2 RX（DMA）→ `g_uartrx` → CDC IN。
- 波特率由主机 `SET_LINE_CODING` 决定。
- **UART2 时钟（默认 80MHz，符合手册）**：`PLL0CLK0(720M)/9 = 80MHz`，
  硬件/软件上限 `uart_clk/8 = 10Mbps`；`UART2_CLK_DIV=9`、`UART2_MAX_BAUDRATE=10000000`。
- `UART2_OVERCLOCK=1` 时改用 `720/4 = 180MHz`（**超出手册限制，不保证所有芯片稳定**），
  上限 22.5Mbps，且 11.25/15/18Mbps 等可精确生成。
  通过 `CMakeLists.txt` 里 `sdk_compile_definitions(-DUART2_OVERCLOCK=1)` 打开。
- 无法精确生成的按就近取整（`uart2_round_baudrate()`）；实际值存于 `g_uart2_applied_baud`。

### cdc_interface.c 重要实现点（历史坑）
- `uartx_preinit()` 必须在 `chry_dap_init()` **之后**调用（`DAP_SETUP()` 会把 PA08/09 设为 GPIO），见 `src/main.c`。
- 必须先 `dma_mgr_init()`，否则 `dma_mgr_request_resource()` 全部失败、TX/RX DMA 不工作。
- RX 采用 **DMAV2 infinite-loop 圆形缓冲**（`en_infiniteloop=true`，`UART_RX_DMA_BUFFER_SIZE=8192`）：
  硬件自动回卷，软件不做 disable/restart。
  - 写入位置用 DMA 的 live `CHCTRL.DSTADDR - buf_base`；小于读位置时按“尾部 + 头部”两段 flush。
  - `en_infiniteloop` 要求 `linked_ptr == 0`，仅 DMAV2 支持。
- **定时器驱动 flush（关键）**：SWD 的延迟采样会在临界区里关总中断，IDLE/满缓冲中断会被抖动。
  因此用 `GPTMR0` 的 **reload 中断** 周期触发 `uart_flush_timer_isr()`，把 DMA 缓冲里的数据搬进
  `g_uartrx`，不再依赖 UART IDLE 和 buffer-full 两个中断。
  - 周期**按当前波特率动态设置**：目标每次 flush 约 `UART_FLUSH_TARGET_BYTES`(1024) 字节，
    `interval_us = 1024*10*1e6/baud`，限制在 `[200us, 10ms]`；低波特率不会过度打扰 CPU。
    `uart_flush_timer_set_baud()` 在 `SET_LINE_CODING` 后按实际波特率调用，
    用 `gptmr_channel_config_update_reload()` 只改 RLD（reload 中断周期随之改变）。
    实测：9600→10ms，9M→1.14ms，22.5M→455us。
  - RX DMA 缓冲 `UART_RX_DMA_BUFFER_SIZE=16384`（≥ 2 个 flush 周期数据 + 余量）。
  - `g_uartrx` 放大到 32KB 以吸收主循环被 SWD 阻塞的时间。
- **`g_uartrx` 所有读写必须在临界区**：生产者是 DMA TC / 定时器 / IDLE / 主循环轮询，
  消费者是 USB IN 完成回调和主循环；`chry_ringbuffer` 非线程安全。
  历史上漏掉 DMA TC 回调的临界区会导致 ring 索引错乱、CDC 多发字节（掉/重数据）。
- `uartx_rx_dma_restart()` 仅在波特率改变时清空 ringbuffer 并重启 RX。
- `PORT_SWD_SETUP()` **不要**再配置 TDI/TDO（PA08/09）：SWD 不用它们，反复 `DAP_Connect`
  重新配置会把 UART2 引脚打断造成丢字节。由 `uartx_enter_com_mode()` 负责保持为 UART2。
- DTR/RTS 默认不驱动（`UART2_DRIVE_DTR_RTS=0`），本板无对应网络。

### 波特率钳制与就近取整
- 软件上限 `UART2_MAX_BAUDRATE`：默认 `10000000`(10M)，`UART2_OVERCLOCK=1` 时 `22500000`；
  主机请求超过上限一律钳到上限。
- `uart2_round_baudrate()` 在 `osc∈{8..30 偶数}`、`div∈[1,0xFFFF]` 中取
  `|uart_clk/(div*osc) - 目标|` 最小的可达波特率（不套用 SDK 的 3% 容差），
  无法整除的速率会落到最近的可达值。
- 实际写入的波特率存于全局 `g_uart2_applied_baud`（可用 J-Link/GDB 读取核对）。

### 串口速率上限与回环测试
- 硬件公式：`baud = uart_clk / (div * osc)`，`osc` 为 8~30 偶数；硬件上限 = `uart_clk / 8`。
- 默认 UART2 时钟 = `PLL0CLK0(720MHz)/9 = 80MHz`（手册上限）→ 上限 **10 Mbps**；
  `UART2_OVERCLOCK=1` → `720/4 = 180MHz` → 上限 **22.5 Mbps**（超规格）。
- 实测（默认 80MHz，详见 `script_test/uart_loopback_common.py`）：9600~10M 全部 OK；
  10M 线速效率 ~99.6%；>10M 的请求被钳到 10M。
- 回归脚本（PA08/PA09 短接）：
  - `script_test/uart_loopback_common.py`：常见速率 + 请求/实际波特率/误差/吞吐 详细表。
  - `script_test/uart_loopback.py` / `uart_loopback_hs.py`：低/高速压力回环。
  - `script_test/test_modeswitch.py`：JTAG/SWD/空闲 引脚复用切换。

### CDC + SWD 同时满载测试
用 `script_test/swd/run_benchmark.py <kHz> <rounds>`（基于 `benchmark_readback.tcl`）做 SWD 读写校验，
同时用 `script_test/uart_stress_stream.py COM75 9000000 <秒>` 连续灌 CDC 数据做回环比对。
SWD 目标可为 STM32F1 等；本板 SWD 实跑 20/36/45/60MHz。

实测结论（SWD 1000 轮 + CDC 9Mbps 连续流，全部 OK，无掉数据）：
- 20MHz / 36MHz / 45MHz / 60MHz SWD 均 1000/1000 PASS。
- CDC 每轮约 7~10MB 连续回环，`rx==sent`、无重复/丢失。
- SWD 写/读吞吐：20M≈1.5/1.4，45M≈2.8/2.3，60M≈3.4/2.8 MiB/s（取决于目标）。
- 要突破 9M 上限需同时调大 `UART2_MAX_BAUDRATE` 并提高 UART 时钟
  （如 720/4=180MHz），且必须确认不超过 UART 外设数据手册的输入时钟上限（当前 SDK 未给出）。

---

## 9. 常见坑（务必遵守）

1. **只支持 JTAG**：本 J-Link 走 SWD 无法连接，且 JTAG 必须 `jtagconf -1 -1` 自动探测，否则停在交互提示。
2. **不要用 `erase` 全片擦除**：J-Link 对本板 QSPI 报 "Only internal flash banks will be erased"，
   `exec EnableEraseAllFlashBanks` + `erase` 会**卡住**。只用 `loadfile`，它会自动擦写到的扇区。
3. **必须加 `-NoGui 1 -ExitOnError 1`**：否则可能弹窗阻塞脚本；脚本内用 `Sleep` 加延时。
4. **必须用打包镜像烧录**（`*_pack.hex` / `*_pack.bin`）：App 头/BL 信息块由 `pack.py` 注入，
   直接烧未打包镜像会被 Bootloader CRC 校验拒绝并停留 DFU。
5. **APP 基址 `0x80020000`、入口 `0x80020100`**：靠 bootloader 跳转；不要用 flash_xip 放到 `0x80000000`；
   改入口/头需同步改 bootloader 的 `app_image_valid()` 与 `hpm_dfu_jump_to_app()`。
6. `.vscode/` 被 `.gitignore` 忽略，配置改了不会进 git。
7. `application_5301/CMakeLists.txt`：`_dfu_bl_length=0x20000` + `_flash_size=0xFE000`（尾部 8K EasyFlash）
   仅用于非 `flash_xip`；并用 `CUSTOM_GCC_LINKER_FILE=linker/flash_dfu_app.ld`。改链接脚本时别破坏这些。
8. **DFU 保护**：Bootloader 的 `dfu_flash_port.c` 把擦写限制在 `< 0x800FE000`，DfuSe 描述也扣除了尾部 8K；
   不要用整片全量 DFU 覆盖 EasyFlash 区（Bootloader 也会拒绝越界擦写）。

---

## 10. 修改代码时的自检

1. `firmware\application_5301\build_dfu.bat` 与 `firmware\bootloader_dfu\build_xip.bat` 能过，
   且输出 `[pack app]` / `[pack boot]`（含 ver/len/crc/time）。
2. 烧录**打包镜像**后设备枚举正常（APP：`VID_0D28 PID_0204`；校验失败/升级模式：`PID_0207` 复合 DFU+MSC）。
3. 破坏 APP 头后复位应停留 Bootloader（完整性保护生效）。
4. VSCode F5 能在 `main` 命中断点。
5. 串口回环（RXD-TXD 短接）在 SWD/空闲下能通过，JTAG 下无回显。
6. HID `0x12`–`0x17` 返回 `version.json` 中配置的版本/时间。
7. APP 已移除 `build.bat` / `build_zcc.bat`：统一用 `build_dfu.bat` 构建，`program.bat`（dfu-util）或 `flash_jlink.bat`（J-Link）烧录；均使用 `_pack` 产物。

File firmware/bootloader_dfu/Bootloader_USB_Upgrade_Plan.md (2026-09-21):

# Bootloader U 盘升级（MSC + 虚拟 FAT）方案

> 参考：`X:\cproject\Debugger\akaLinkCompact\firmware\Bootloader`（CH32V305）
> 目标：为 HPM5301 bootloader 增加 MSC 枚举，U 盘内含 `INFO.TXT` 与网页快捷方式，支持拖拽升级。
> 状态：**已实施并验证通过**

## 0. 实施结果

- USB：**复合 DFU + MSC**，最终 PID **`0x0207`**（0x0205 为旧 DFU-only；0x0206 在开发期被 Windows
  缓存了旧 OS 描述符）。MI_00=DFU（WinUSB，经 MS OS 2.0/WCID 自动安装）、MI_01=MSC。
- U 盘：128MB FAT16（卷标 `AKALINKPRO`），`INFO.TXT` / `AKALINK.URL` / `AKALINK.HTM`。
- 拖拽升级：任意 `*.BIN` → 按 FAT 链写入 APP 区（跳过 `System Volume Information`）→ 延时 1s 复位 → 校验跳转。
- `dfu-util -l` / `-D _pack.bin` 均可用。
- 虚拟 FAT：标准 FAT16 512B 扇区，64 sectors/cluster，RAM 元数据（boot/FAT/root），数据簇映射 APP flash；
  写上限 `APP_MAX = 0x800FE000 - 0x80020000`，**不触碰尾部 EasyFlash/保留区**。
- 需成对升级：Bootloader 与 APP 的头格式/入口 `0x80020100`。

---

## 1. 参考工程做法（CH32V305）

- Bootloader **MSC-only**（VID 0D28 / PID 0204），枚举成一个 64×2048B 的虚拟 FAT16 盘。
- `vfat/flash_fat16.c`：静态数组提供 boot sector / FAT / root dir / 一个文本文件；
  `usbd_msc_sector_read/write` 把逻辑块映射到这些数组与 flash。
- root 目录写入时识别 `*.BIN` 文件名与 `file_size`；后续数据写入按偏移写到 APP flash
  （`VFAT16_FLASH_START_ADDR`），写满后置 `g_app_download_finished=1`，主循环延时 2s 复位。
- `fat16_file_init()` 填充 info 文本：芯片 UID、HWVER、BLVER、FWVER、CRC 状态。
- **不足**：没有网页快捷方式；FAT/FAT 写入被忽略（一致性弱）；仅 MSC，无 DFU。

---

## 2. 拟采用的 HPM5301 设计

### 2.1 USB 拓扑（需确认，见 §5-Q1）

推荐 **复合设备：DFU + MSC**，保持现有 dfu-util 路径可用，同时出现 U 盘：
- 接口 0：DFU（`usbd_dfu_init_intf`，仅 EP0）—— 保留。
- 接口 1：MSC（`usbd_msc_init_intf`，2 个 bulk EP，如 `0x81`/`0x02`）。
- 描述符参考 `application_5301/src/usb/usb_composite.c` 的 composite 写法（含 `MSC_DESCRIPTOR_INIT`）。
- VID/PID 保持 bootloader 的 `0D28:0205`；Product 改为 `akaLinkPro U-Disk` / `akaLinkPro DFU`。

### 2.2 虚拟文件系统（RAM 元数据 + flash 数据区）

采用**标准 FAT16、512B 扇区**，元数据放在 RAM 缓冲区，数据簇直接映射 APP flash：

| 区域 | 位置 | 说明 |
| --- | --- | --- |
| Boot 扇区 | RAM，LBA 0 | 标准 BPB（512B/sector, 8 sec/cluster, 2 FAT, 512 root entries, 卷 16MB 以便判定为 FAT16） |
| FAT1/FAT2 | RAM | 初始化时写入卷标 + 两个文件 + 升级文件的簇链 |
| 根目录 | RAM | `INFO.TXT`、`AKALINK.URL`（+ 主机新建的升级文件） |
| 数据簇 0.. | 文件内容 | `INFO.TXT`/`URL` 由 RAM 生成；升级文件簇 → 直接读写 APP flash |

- 卷大小：报告 16MB（512B×32768），保证主机按 FAT16 挂载；未使用扇区读返回 0、写忽略。
- **`INFO.TXT`** 内容（示例）：
  ```
  SN:XXXXXXXXXXXX
  HWVER:A.0
  BLVER:1.0
  FWVER:0.1
  DESC:akaLinkPro CMSIS-DAP
  CRC32:pass|fail
  Drop a .bin firmware here to upgrade.
  ```
  数据来源：OTP UID（`drv_read_uid`/`otp`）、boot info 块 `0x8001F000`、APP 头 `0x80020000`（CRC 校验状态）。
- **网页快捷方式**：`AKALINK.URL`（Windows Internet Shortcut）
  ```
  [InternetShortcut]\r\nURL=https://akkako.github.io/akaLinkPro/\r\n
  ```
  （如需跨平台可另加 `AKALINK.HTM` 做 meta 跳转，见 §5-Q3。）

### 2.3 U 盘升级流程

1. 主机把 `akaLinkPro_App_pack.bin` 拖入 U 盘 → 在根目录新建一个 `*.BIN`。
2. 根目录写入回调解析新条目，记录 `start_cluster`/`file_size`，并把该文件数据区映射到
   `APP_BASE(0x80020000)` 起；数据写入经 `dfu_flash_port`/ROM API 擦写 APP 区。
3. 文件写满 → 置 `g_app_download_finished`；主循环延时 ~2s（等主机 flush）后复位。
4. Bootloader 复位后按 `app_image_valid()` 校验（签名+长度+CRC32）→ 通过则跳转，失败停留并再次提供 U 盘。

> 升级镜像必须是**打包镜像**（含 256B 头），与 J-Link/dfu-util 一致。

### 2.4 LED 提示（可选）

- 进入 Bootloader：双灯慢闪（现状）。
- U 盘挂载/可写：可约定某种闪法。
- 升级写入中/完成：可约定（见 §5-Q4）。

---

## 3. 涉及文件

| 文件 | 改动 |
| --- | --- |
| `bootloader_dfu/src/usb_config.h` | 打开 `CONFIG_USB_DEVICE_MSC` |
| `bootloader_dfu/CMakeLists.txt` | 加入 `src/vfat.c`、`src/msc_if.c`（MSC 类由 SDK 按 `CONFIG_USB_DEVICE_MSC` 编译） |
| `bootloader_dfu/src/dfu_desc.c` | 改为 DFU+MSC 复合描述符；注册两个接口 |
| `bootloader_dfu/src/main.c` | 初始化 DFU+MSC；主循环处理升级完成复位 |
| `bootloader_dfu/src/vfat.c/.h` | 新增：RAM FAT16 元数据 + `INFO.TXT`/`URL` 生成 + 数据簇→APP flash 映射 |
| `bootloader_dfu/src/msc_if.c` | 新增：`usbd_msc_get_cap/sector_read/sector_write` |
| `bootloader_dfu/src/boot_port_board_hpm.c` | 读取 OTP UID（序列号）如需 |
| 文档 | 新增本文件；更新 `SKILL.md`（bootloader 变复合 DFU+MSC、U 盘说明） |

---

## 4. 风险 / 注意

1. 改动 USB 描述符有**破坏现有 dfu-util 升级**的风险，需两种方式都回归。
2. 主机对 FAT16 的一致性要求：必须正确维护 FAT/根目录/簇链；否则 Windows 可能报“需要格式化”。
3. 升级写入与 DFU 写入共用 APP 区，需保证互斥（同一时刻只走一种）。
4. 升级中掉电：APP 头/CRC 不完整 → Bootloader 校验失败，停留 U 盘，可重试。
5. 写 flash 时中断/耗时（扇区擦除）与 MSC 事务的时序。
6. 大文件（107KB ≈ 214×512B 扇区）需要正确的簇链与顺序写入。

---

## 5. 待确认

- **Q1 USB 拓扑**：复合 **DFU+MSC**（推荐，保留 dfu-util）？还是 MSC-only（替换 DFU）？
- **Q2 虚拟 FAT 规格**：标准 FAT16/512B（推荐）/ 参考工程的 FAT16/2048B / FAT12 软盘镜像？
- **Q3 快捷方式文件**：仅 `AKALINK.URL`（Windows）？还是再附一个 `AKALINK.HTM`（跨平台 meta 跳转）？
- **Q4 升级完成行为**：写满即延时 2s 复位（参考做法，推荐）？是否需要 LED 指示/更长时间？
- **Q5 升级文件名**：接受任意 `*.BIN`（参考做法）？还是仅接受固定名 `FIRMWARE.BIN`（更可控）？

确认后按 §3 实施，并用 Windows 挂载 → 读取文件 → 拖拽升级 全流程回归。

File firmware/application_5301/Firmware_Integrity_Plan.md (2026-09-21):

# HPM5301 固件完整性校验 / 版本信息嵌入 方案计划

> 参考工程：`X:\cproject\Debugger\akaLinkCompact\firmware`（CH32V305 CMSIS-DAP）
> 目标工程：`X:\cproject\Debugger\akaLinkPro\firmware`（HPM5301 CMSIS-DAP）
> 状态：**已实施并自检通过**（见 §8）

---

## 0. 已确认决策（评审记录）

| # | 议题 | 决策 |
| --- | --- | --- |
| 1 | APP 完整性校验主体 | **仅由 Bootloader 校验**；校验失败**停留在 Bootloader（DFU）** |
| 2 | Bootloader 自身校验 | **不做** |
| 3 | 版本/描述/硬件版本配置源 | **待定**（见 §7-Q3） |
| 4 | 编译时间格式 | `YYYY/MM/DD HH:MM:SS` |
| 5 | 头/信息块大小、入口偏移 | **256 B 头、入口 `+0x100`**；已验证 HPM 可支持（见 §4.4） |
| 6 | Bootloader 信息块位置 | Bootloader 区尾 `0x8001F000` |
| 7 | APP 链接方式 | **自定义链接脚本**（`linker/flash_dfu_app.ld`） |
| 8 | 校验失败的状态提示 | 预留状态变量，后续再定义 |

### 4.4 可行性验证结果（入口 `+0x100`）

已用自定义链接脚本原型验证（`CUSTOM_GCC_LINKER_FILE=linker/flash_dfu_app.ld`，`.start` 中签名后 `. = ALIGN(0x100)`）：

| 检查项 | 结果 |
| --- | --- |
| ELF Entry point | `0x80020100` ✅ |
| `.start` 段 | `0x80020000`，大小 `0x150`（0x100 头 + 0x50 代码）✅ |
| `dfu_signature` | `0x80020000` = `21 4D 50 48` ✅ |
| `_start` | `0x80020100` ✅ |
| `0x80020004`–`0x800200FF` | 链接器填充 `0x00`，由 `pack` 覆写 ✅ |
| 编译 | 通过（FLASH 888 KB 区） ✅ |

**结论：HPM5301 支持 256 B 头 + 入口 `0x100` 的方案，沿用 `0x100`。**

---

## 1. 参考工程 akaLinkCompact (CH32V305) 调研

### 1.1 Flash 布局与地址选择

CH32V305 为 **128 KB Flash**（`0x00000000`–`0x0001FFFF`），规划如下：

| 区域 | 起始 | 结束 | 大小 | 说明 |
| --- | --- | --- | --- | --- |
| Bootloader 代码 | `0x00000000` | `0x00003EE3` | ~15.7 KB | 链接区 `LENGTH=0x3EE4` |
| Bootloader 版本串 | `0x00003EE4` | `0x00003EEB` | 8 B | `pack.py` 写入 |
| Bootloader 编译时间 | `0x00003EEC` | `0x00003EFF` | 20 B | `YYYY/MM/DD HH:MM:SS` + `\0` |
| 硬件版本串 | `0x00003F00` | `0x00003F07` | 8 B | 板级信息 |
| 硬件生产日期 | `0x00003F08` | `0x00003F1B` | 20 B | 板级信息 |
| （填充至 16 KB） | `0x00003F1C` | `0x00003FFF` | — | 0xFF |
| **APP 头** | `0x00004000` | `0x000040FF` | 256 B | 长度/CRC/版本/日期/描述 |
| APP 代码 | `0x00004100` | `0x0001FEFF` | 114 KB | 链接区 `ORIGIN=0x4100` |
| 参数存储页 | `0x0001FF00` | `0x0001FFFF` | 256 B | 单页配置 |

**APP 头结构（256 B，`pack.py` 生成）**

| 偏移 | 长度 | 字段 |
| --- | --- | --- |
| `0x00` | 4 | APP 代码长度 `app_len`（LE） |
| `0x04` | 4 | APP 代码 CRC32（LE） |
| `0x08` | 8 | 固件版本串 |
| `0x10` | 20 | 固件编译时间 |
| `0x24` | 24 | 固件描述串 |
| `0x3C`–`0xFF` | — | 0x00/0xFF 填充 |

> 注意：APP 头**不在** ELF 链接镜像内；APP 链接到 `0x4100`，`pack.py` 在二进制前**追加** 256 B 头，烧录到 `0x4000`，因此代码落到 `0x4100`。

### 1.2 信息嵌入机制

构建后处理脚本 `Bootloader/proj/pack.py`、`Application/proj/pack.py`（Makefile 的 `POST_BUILD` 调用）：

| 脚本 | 动作 |
| --- | --- |
| Bootloader `pack.py` | 读取原始 bin → 截断到 `0x3EE4` → 在 `0x3EE4/0x3EEC/0x3F00/0x3F08` 写入版本/时间 → 补足到 `0x4000` |
| Application `pack.py` | 计算 `app_len` 与 CRC32 → 生成 256 B 头 + 代码，输出 `*_pack.bin` |

- 版本号、描述在 `pack.py` 里以常量配置（`bl_ver_str='1.02'`、`fw_ver_str='0.02'`、`hw_ver_str='A.01'`、`desc_str`）。
- 编译时间取**打包时刻** `datetime.now()`，格式 `%Y/%m/%d %H:%M:%S`。
- CRC32 种子 `0x0D000721`，算法等价于 Python `binascii.crc32(data, 0x0D000721)`。

### 1.3 Bootloader 完整性校验流程

`Bootloader/app/main.c::check_app_integrity()`：

1. 读 `0x4000` 得 `app_length`；若 `> APPLICATION_MAX_SIZE` → 判定失败；
2. 读 `0x4004` 得 `file_crc32`；
3. `calc = crc32(0x0D000721, (uint8_t*)0x4100, app_length)`；
4. `calc == file_crc32` 则校验通过。

Bootloader 主流程：校验失败 / BKP 触发 / 看门狗异常复位 三者任一 → 停留在 Bootloader（USB MSC/FAT16 升级）；否则跳转 APP（软件中断跳到 `0x4100`）。

### 1.4 APP 侧读取方式

APP 直接以**绝对地址**读取元数据（`sys_config.h`）：

| 宏 | 地址 | 内容 |
| --- | --- | --- |
| `BOOTLOADER_VER_STR_ADDR` | `0x3EE4` | Bootloader 版本 |
| `BOOTLOADER_TS_STR_ADDR` | `0x3EEC` | Bootloader 编译时间 |
| `HARDWARE_VER_STR_ADDR` | `0x3F00` | 硬件版本 |
| `HARDWARE_PROD_TS_STR_ADDR` | `0x3F08` | 生产日期 |
| `APPLICATION_VER_STR_ADDR` | `0x4008` | 固件版本 |
| `APPLICATION_TS_STR_ADDR` | `0x4010` | 固件编译时间 |
| `APPLICATION_DESC_STR_ADDR` | `0x4024` | 固件描述 |

HID 的 `0x12`–`0x17` 指令即从这些地址取字符串返回；App 自身配置存于最后一页 `0x1FF00`。

### 1.5 小结（可复用的设计点）

1. **固定地址元数据块**：Bootloader 信息块 + APP 头块，构建后由 `pack.py` 填充。
2. **APP 头在代码之前 256 B**，长度 + CRC + 版本/时间/描述。
3. **Bootloader 启动时校验 APP 长度 + CRC32**，失败则留在 Bootloader。
4. **CRC32 带固定种子**，PC 端与 MCU 端算法一致。
5. 编译时间/版本在**打包阶段**统一注入，固件源码不硬编码。

---

## 2. HPM5301 工程现状

### 2.1 当前 Flash 布局（1 MB QSPI NOR，`0x80000000`）

| 区域 | 地址范围 | 大小 | 说明 |
| --- | --- | --- | --- |
| Bootloader | `0x80000000`–`0x8001FFFF` | 128 KB | ROM 由 `nor_cfg_option@0x400`、`boot_header@0x1000` 引导；实际代码 ~40 KB |
| APP | `0x80020000`–`0x800FDFFF` | 888 KB | 链接区；实际 ~81 KB |
| EasyFlash 配置区 | `0x800FE000`–`0x800FFFFF` | 8 KB | 2×4 KB 扇区，磨损平衡 |

### 2.2 与参考工程的差异 / 现状问题

| 项 | CH32V305 | HPM5301 现状 |
| --- | --- | --- |
| APP 头部 | `0x4000` 256 B 头 + `0x4100` 代码 | **无**；首 4 字节仅 DFU 签名 `0x48504D21`，入口 `+4` |
| APP 完整性校验 | Bootloader 校验长度+CRC | **无**（仅校验 4 字节签名） |
| 版本/日期 | 打包注入，绝对地址读取 | **源码硬编码字符串**（`api_param.c` 宏） |
| Bootloader 信息 | `0x3EE4` 起 | **无** |
| 硬件版本/生产日期 | Bootloader 区 | **源码硬编码** |
| 参数存储 | 最后一页 | EasyFlash（已实现，2 扇区） |

> HPM ROM 只引导 **Bootloader**（`boot_header`），APP 完全由 Bootloader 跳转，因此 APP 头/入口可自由规划。

---

## 3. 目标

1. APP 固件嵌入：**长度 + CRC32 + 版本 + 编译日期时间 + 描述**，固定地址可读；
2. Bootloader 嵌入：**版本 + 编译日期时间**；板级：**硬件版本 + 生产日期**；
3. Bootloader 启动时**校验 APP 完整性**（长度 + CRC32），失败则停留在 Bootloader 便于升级；
4. APP 侧 HID `0x12`–`0x17` 改为读取上述元数据；
5. 不破坏现有 DFU、EasyFlash、尾部 8 KB 保留与 J-Link 流程。

---

## 4. 建议方案（推荐方案 A）

### 4.1 新地址分布

| 区域 | 地址范围 | 大小 | 说明 |
| --- | --- | --- | --- |
| Bootloader 代码 | `0x80000000`–`0x8001EFFF` | < 124 KB | 链接区，正常 ~40 KB |
| **Bootloader 信息块** | `0x8001F000`–`0x8001F0FF` | 256 B | 版本/编译时间/硬件版本/生产日期（扇区其余保留） |
| **APP 头** | `0x80020000`–`0x800200FF` | 256 B | `0x00` DFU 签名 + 长度 + CRC + 版本/时间/描述 |
| APP 代码 | `0x80020100`–`0x800FDFFF` | ~888 KB | 链接入口 `0x80020100` |
| EasyFlash 配置区 | `0x800FE000`–`0x800FFFFF` | 8 KB | 不变 |

### 4.2 APP 头结构（`0x80020000`，256 B）

| 偏移 | 长度 | 字段 | 说明 |
| --- | --- | --- | --- |
| `0x00` | 4 | DFU 签名 | `0x48504D21`（"HPM!"），**保持不变** |
| `0x04` | 4 | `app_code_len` | 代码字节数（从 `0x80020100` 起） |
| `0x08` | 4 | `app_crc32` | CRC32（种子 `0x0D000721`，仅覆盖代码） |
| `0x0C` | 4 | `header_ver` | 头格式版本 = 1 |
| `0x10` | 8 | `fw_ver_str` | 固件版本，如 `0.1`+\0 |
| `0x18` | 20 | `fw_build_time` | `YYYY/MM/DD HH:MM:SS`+\0 |
| `0x2C` | 24 | `fw_desc` | 如 `akaLinkPro CMSIS-DAP` |
| `0x44` | 0xBC | reserved | 0xFF |

### 4.3 Bootloader 信息块（`0x8001F000`，256 B）

| 偏移 | 长度 | 字段 |
| --- | --- | --- |
| `0x00` | 4 | magic `"BLI1"` = `0x31494C42` |
| `0x04` | 4 | `bl_code_len` |
| `0x08` | 4 | `bl_crc32`（可选） |
| `0x0C` | 4 | `format_ver` = 1 |
| `0x10` | 8 | `bl_ver_str` |
| `0x18` | 20 | `bl_build_time` |
| `0x2C` | 8 | `hw_ver_str` |
| `0x34` | 20 | `hw_prod_date` |
| `0x48` | 0xB8 | reserved |

### 4.4 APP 链接与入口调整（推荐：自定义链接脚本）

- 复制 SDK `flash_dfu.ld` 到工程（如 `application_5301/linker/flash_dfu_app.ld`），仅改 `.start`：

```
.start : {
    KEEP(*(.dfu_signature))     /* 0x80020000 : 4 B 签名 */
    . = ALIGN(0x100);           /* 保留 0x80020004-0x800200FF 给 APP 头 */
    KEEP(*(.start))             /* 0x80020100 : 入口 */
    . = ALIGN(8);
} > FLASH
```

- `CMakeLists.txt` 设置 `CUSTOM_GCC_LINKER_FILE=<绝对路径>`（SDK 支持，已验证机制）。
- APP 入口由 `0x80020004` 变为 `0x80020100`；APP 自身可用固定地址直接读自己的头。
- 保留 `_flash_size=0xFE000` 尾部 8 KB 预留。

> 备选方案 B：不改链接脚本，把 `_dfu_bl_length` 改为 `0x20100` 使 APP 链接到 `0x80020100`，
> 去掉 ELF 中的 `.dfu_signature`，由 `pack.py` 在镜像前追加 256 B 头（与 CH32V 完全一致）。
> 缺点：APP ELF 不再包含头/签名，且需移除 board.c 的 `.dfu_signature`。

### 4.5 构建注入流程（pack）

新增打包脚本（如 `application_5301/proj/pack_app.py`、`bootloader_dfu/proj/pack_bl.py`），由 CMake `POST_BUILD` 调用：

| 目标 | 输入 | 处理 | 输出 |
| --- | --- | --- | --- |
| APP | `akaLinkPro_App.bin`（含头占位） | `app_code_len = size-0x100`；CRC32(代码)；填头字段 版本/时间/描述 | `..._pack.bin` / `..._pack.hex` |
| Bootloader | `akaLinkPro_Boot.bin` | 在 `0x8001F000` 写信息块（版本/时间/硬件版本/生产日期） | `..._pack.bin` / `..._pack.hex` |

- 版本号等集中配置（建议 `proj/version.json` 或 CMake 变量，供两脚本读取），编译时间取打包时刻。
- CRC 与 MCU 端一致：`binascii.crc32(data, 0x0D000721)`。
- hex 由「打包后的 bin」转换（`objcopy -I binary -O ihex --change-addresses <base>`），保证 J-Link/dfu-util 使用同一镜像。

### 4.6 Bootloader 校验流程（改动点）

`bootloader_dfu/src/hpm_dfu_trigger.c::hpm_dfu_check_bootloader_request()`：

```
#define APP_BASE      0x80020000
#define APP_CODE      (APP_BASE + 0x100)
#define APP_MAX_LEN   (0x800FE000 - APP_CODE)     /* 0xDDF00 */

读 0x80020000 == BOARD_DFU_SIGNATURE ? 否则停留 DFU
len = *(u32*)(APP_BASE+4); crc = *(u32*)(APP_BASE+8);
若 len==0 || len>APP_MAX_LEN || header_ver!=1        -> 失败，停留 DFU
l1c_dc_invalidate(APP_CODE, len)
crc32_seed(0x0D000721, APP_CODE, len) == crc ? 成功 -> 跳转 APP_CODE
```

- 跳转地址 `hpm_dfu_jump_to_app()` 由 `+4` 改为 `+0x100`。
- 新增一个带种子的 CRC32 实现（可参考 SDK `hpm_crc32.c`，加种子与末尾取反）。
- 校验失败行为：**停留在 Bootloader（DFU 模式）**，便于重新烧录。

### 4.7 APP 侧读取（HID 改造）

`src/api/api_param.c` 中：

- `APPLICATION_VER_STR_ADDR` → `0x80020010`
- `APPLICATION_TS_STR_ADDR` → `0x80020018`
- `APPLICATION_DESC_STR_ADDR` → `0x8002002C`
- `BOOTLOADER_VER_STR_ADDR` → `0x8001F010`
- `BOOTLOADER_TS_STR_ADDR` → `0x8001F018`
- `HARDWARE_VER_STR_ADDR` → `0x8001F02C`
- `HARDWARE_PROD_TS_STR_ADDR` → `0x8001F034`

读取方式：直接 XIP 读（必要时 `l1c_dc_invalidate`），或经 `drv_flash_read`。HID `0x12`–`0x17` 逻辑不变。

### 4.8 烧录流程影响

| 方式 | 现状 | 改后 |
| --- | --- | --- |
| J-Link APP | `loadfile App.hex` | `loadbin App_pack.bin,0x80020000`（或 pack 后的 hex） |
| J-Link Bootloader | `loadfile Boot.hex` | `loadbin Boot_pack.bin,0x80000000`（含 `0x8001F000` 信息块） |
| dfu-util | `-D App.bin -s 0x80020000:leave` | `-D App_pack.bin` |
| DFU 描述 | 可写区结尾扣 8 KB | 不变 |

---

## 5. 实施步骤（建议顺序）

1. **APP 链接脚本**：新增自定义 `flash_dfu_app.ld` + `CUSTOM_GCC_LINKER_FILE`，把入口改到 `0x80020100`，验证可正常启动（Bootloader 临时改跳 `+0x100`）。
2. **Bootloader 信息块 + APP 头写入**：编写 `pack_bl.py` / `pack_app.py`，接入 CMake POST_BUILD。
3. **Bootloader 校验**：加入长度 + CRC32 校验，失败停留 DFU；更新跳转地址。
4. **APP 读取改造**：HID `0x12`–`0x17` 改为读固定地址元数据。
5. **工具链脚本**：更新 `flash_jlink.bat`、`build.bat`/`build_dfu.bat`、`dfu_desc.c` 说明。
6. **文档**：更新 `Flash_Memory_Map.md`、`Custom HID Protocol.md`（如版本字段来源变化）。
7. **回归测试**：正常启动、CRC 破坏后停留 DFU、DFU 升级、EasyFlash 配置持久化、HID 版本读取。

---

## 6. 风险与注意事项

1. **入口迁移**：改链接脚本后必须确认 `_start`/向量表加载地址正确（`.vectors` 的 `AT>` 紧随 `.start`）。
2. **CRC 覆盖范围**：仅覆盖代码区（`0x80020100` 起 `app_code_len`），PC 端与 MCU 端必须完全一致；bin 空隙填充需确定（0x00/0xFF）。
3. **Cache 一致性**：校验前 `l1c_dc_invalidate`，写入后 `fence.i`（现有 drv/DFU 已有）。
4. **信息块扇区保护**：`0x8001F000` 属 Bootloader 区，APP DFU 不会写；确认 Bootloader 代码不越界（当前 ~0x9E00）。
5. **J-Link hex/bin 一致性**：确保 J-Link 与 dfu-util 使用**打包后**的镜像。
6. **版本注入时机**：编译时间以打包时刻为准，避免 C 源码 `__DATE__` 与头内时间不一致。
7. **失败策略**：校验失败停留 DFU；若希望仍可启动需提供「强制启动」入口（可选）。
8. **兼容旧 Bootloader**：Bootloader 与 APP 必须**成对升级**（入口/头格式变更）。

---

## 7. 剩余待确认

- **Q3 版本/描述/硬件版本的唯一配置源**：已采用 `firmware/version.json`
  （字段 `app_fw_ver`、`app_desc`、`bl_ver`、`hw_ver`、`hw_prod_date`），由 app/bootloader 两个
  pack 流程共同读取。

## 8. 实施结果 / 自检

| 项 | 结果 |
| --- | --- |
| APP 自定义链接脚本 | ✅ `linker/flash_dfu_app.ld`，Entry=`0x80020100`，`.start`=`0x80020000`+`0x150` |
| APP 打包 | ✅ `pack.py app` 注入 len/CRC/ver/time/desc，输出 `_pack.bin`/`_pack.hex` |
| Bootloader 打包 | ✅ `pack.py boot` 在 `0x8001F000` 写入信息块，输出 `_pack.hex` |
| Bootloader 校验 | ✅ 签名 + 长度 + CRC32；跳转 `0x80020100` |
| 正常启动 | ✅ 烧录后枚举 `VID_0D28 PID_0204`（APP 运行） |
| 完整性失败 | ✅ 破坏 APP 头/代码后复位 → 停留 Bootloader（`PID_0205` DFU） |
| 恢复 | ✅ 重新烧录 packed APP 后恢复正常 |
| dfu-util 升级 | ✅ `-D _pack.bin -s 0x80020000:leave` 成功，重启后 APP 运行（校验通过） |
| HID 读取元数据 | ✅ `0x12`/`0x13`/`0x14`/`0x15`/`0x16`/`0x17` 分别返回 `A.0`/`0.1`/`1.0`/`2026-08-06`/`2026/09/21 19:50:23`/`2026/09/21 19:50:36` |
| EasyFlash 配置 | ✅ `GET_CONFIG` 返回 `output=0,v5=1,clock=0,led1=4,led2=5,vref=3300`（未受影响） |
| 烧录脚本 | ✅ `flash_jlink.bat`(app/boot)、`build.bat`、`program.bat` 改用 `_pack` 产物 |
| 文档 | ✅ `Flash_Memory_Map.md` 更新（§1/§3/§3.1/§3.2/§3.3/§5/§7） |

未完成（按决策留待后续）：
- 校验失败状态变量 / 指示灯提示（决策 8）。
- Bootloader 自身 CRC（决策 2）。
- APP 自校验（决策 1）。

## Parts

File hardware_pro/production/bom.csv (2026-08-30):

Designator | Footprint | Quantity | Value | LCSC Part #
C1, C10, C104, C105, C107, C109, C11, C111, C112, C114, C115, C116, C117, C118, C121, C129, C130, C131, C139, C144, C15, C3, C5, C6, C7, C8, C9 | 0603 | 27 | 0.1uF
C101, C102 | 0805 | 2 | 22uF
C103 | 0805 | 1 | 10uF
C106, C108, C12, C4 | 0603 | 4 | 4.7uF
C110 | 0603 | 1 | 220pF
C119, C120 | 0603 | 2 | 20pF
C122, C123, C125, C2 | 0603 | 4 | 1uF
C13 | 0603 | 1 | 10nF
C14 | 0603 | 1 | 10pF
D101, D103 | LED_D3.0mm_Clear | 2 | LED
F1 | 0603 | 1 | 500mA
J1 | USB_C_Receptacle_HRO_TYPE-C-31-M-12 | 1 | USB_C_Receptacle_USB2.0_16P
J102 | PinHeader_2x05_P1.27mm_Vertical | 1 | JTAG
J103 | IDC-Header_2x10_P2.54mm_Horizontal | 1 | IDC
L101 | L_Sunlord_SWPA3012S | 1 | 4.7uH
Q1 | SOT-23-3 | 1 | SI2305
Q104 | SOT-23-3 | 1 | AO3400A
R1, R2 | 0603 | 2 | 5.1K
R10, R13 | 0603 | 2 | 4.7K
R101, R103, R104, R110, R117, R133, R4, R5, R8 | 0603 | 9 | 10K
R107, R109 | 0603 | 2 | 3.3K
R113 | 0603 | 1 | 1K
R12, R125, R127, R128, R129, R130, R3 | 0603 | 7 | 22R
R6, R7 | 0603 | 2 | 33R
U1 | SOT-23-3 | 1 | XC6206P332MR
U101 | QFN-48-1EP_6x6mm_P0.4mm_EP4.2x4.2mm | 1 | HPM5301IEG1
U102 | SOT-23-6 | 1 | USBLC6-2SC6
U103, U110, U111, U112, U113, U3 | SOT-23-6 | 6 | SN74LVC1T45DBV
U105 | SOT-23-6 | 1 | TPS22918DBV
U2 | SOT-23-5 | 1 | LMV321
Y101 | Crystal_SMD_3225-4Pin_3.2x2.5mm | 1 | 24MHz

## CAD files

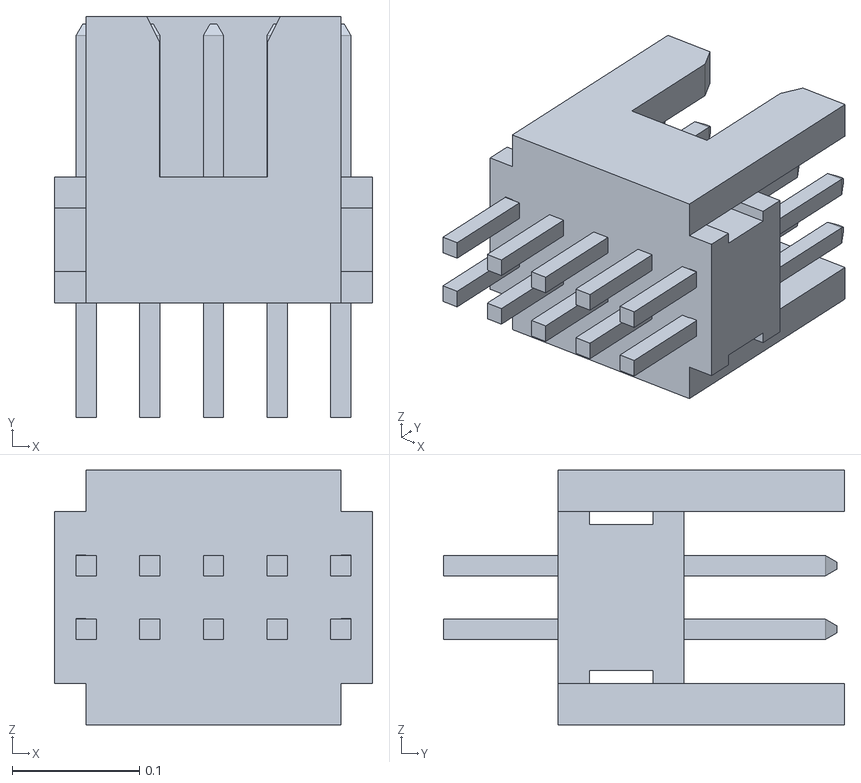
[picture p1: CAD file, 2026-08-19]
hardware_pro/3d/FTSH-105-01-L-D-K.stl
0.25 x 0.315 x 0.2

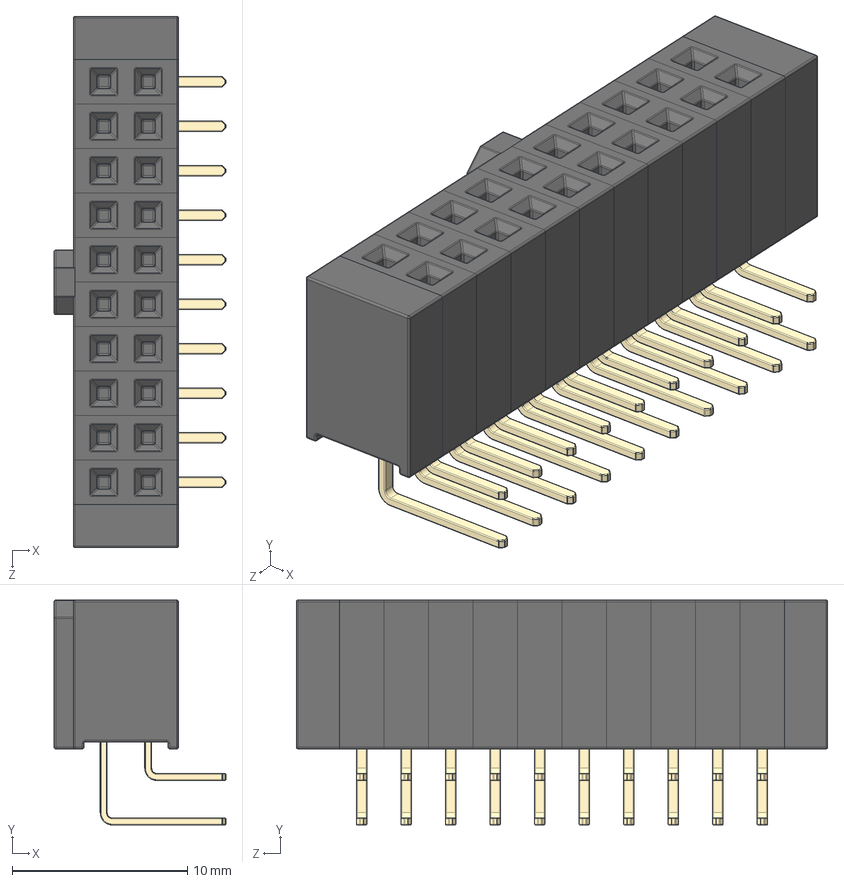
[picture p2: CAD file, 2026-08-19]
hardware_pro/3d/SFH11-xxPC-D10-RA-BK.STEP
9.80 x 12.8 x 30.3 mm
body section with RA gold pins x 10
end x 2
Polarizing Key

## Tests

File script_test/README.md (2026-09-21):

# script_test

akaLinkPro (HPM5301) 固件测试脚本集合。这些脚本用于验证 **UART2 ↔ CDC 串口桥**、
**DAP 模式切换**（SWD/空闲 = UART2，JTAG = FGPIO）以及设备枚举状态。

## 依赖

- Python 3.11 + `pyserial`、`pyusb`（`pip install pyserial pyusb`）
- Windows 上需已安装 libusb/WinUSB 驱动（pyusb 后端）
- 硬件：将 **PA08(TXD) 与 PA09(RXD) 短接**（串口回环）
- 设备运行 `application_5301` 固件，并在系统中枚举出 CDC 串口（COMx）

COM 端口号在不同机器上会变化，脚本支持通过参数传入，默认 `COM75`。

## 脚本说明

| 文件 | 用途 |
| --- | --- |
| `uart_loopback.py` | 串口回环压力测试：逐字节回环 + 大块随机数据流，覆盖 115200~2Mbps |
| `uart_loopback_hs.py` | 高速回环测试：2Mbps~11.25Mbps，含吞吐量与线速效率统计 |
| `uart_loopback_common.py` | 常见速率回环详表：请求/实际波特率、误差、耗时、吞吐、线速效率 |
| `diag_loopback.py` | 单次大流量回环并定位首个错误位置/零区块，用于诊断 DMA 边界问题 |
| `test_modeswitch.py` | 通过 CMSIS-DAP 发 `DAP_Connect`(JTAG/SWD)/`DAP_Disconnect`，验证引脚复用切换 |
| `uart_stress_loop.py` | 定时长回环压测（发一块读一块），统计 errors/late/最大延迟，可区分丢失与延迟 |
| `uart_stress_stream.py` | 连续流回环压测（读线程 + 不丢包比对），用于与 SWD 并发时做满负荷验证 |
| `list_usb.ps1` | 列出 `VID_0D28` 相关 USB 设备与 CDC 端口（状态检查） |
| `hold_port.py` | 打开串口并保持若干秒，便于用 J-Link/GDB 在线检查运行状态 |
| `swd/run_benchmark.py` | 生成指定 `adapter speed`/`iterations` 的 OpenOCD SWD 读写校验并运行 |

### 运行示例

```bat
python script_test\uart_loopback.py COM75
python script_test\uart_loopback_hs.py COM75 262144
python script_test\uart_loopback_common.py COM75
python script_test\diag_loopback.py COM75 115200 32768
python script_test\test_modeswitch.py COM75
powershell -ExecutionPolicy Bypass -File script_test\list_usb.ps1
python script_test\hold_port.py COM75 8
```

### 串口速率上限与就近取整（HPM5301）

- 驱动器公式：`baud = uart_clk / (div * osc)`，`osc` 为 8~30 的偶数。
- **默认（符合手册）**：UART2 时钟 = `PLL0CLK0(720MHz)/9 = 80MHz`（UART 输入时钟手册上限），
  硬件/软件上限 = `uart_clk/8 = 10 Mbps`（`UART2_CLK_DIV=9`、`UART2_MAX_BAUDRATE=10000000`）。
- **超频选项**：`CMakeLists.txt` 里取消注释 `sdk_compile_definitions(-DUART2_OVERCLOCK=1)`，
  则 `720/4 = 180MHz`、上限 22.5 Mbps，且 11.25/15/18 Mbps 可精确生成。
  **注意：180MHz 超出手册限制，不保证所有芯片稳定，仅供测试。**
- 无法精确生成的按**就近取整**（`uart2_round_baudrate()`）。
- 实际写入的波特率存于 `g_uart2_applied_baud`（可用 J-Link/GDB 读取核对）。
- 实测吞吐（默认 80MHz）：10M→~972KB/s（线速效率 99.6%）；>10M 请求被钳到 10M。
  超频 180MHz：22.5M→~2108KB/s。

## gdb/ — 在线调试检查脚本（配合 JLink GDB Server）

先启动 GDB Server（或用 `firmware/application_5301/gdb_server.bat`）：

```
JLinkGDBServerCL.exe -device HPM5301xEGx -if JTAG -speed 4000 -port 2331 -nogui -singlerun
```

然后：

```bat
riscv32-unknown-elf-gdb -batch -x script_test\gdb\<script>.gdb ^
  firmware\application_5301\build_dfu\output\akaLinkPro_App.elf
```

| 文件 | 用途 |
| --- | --- |
| `dbg_app.gdb` | 连接/复位/load/命中断点 main（与 VSCode launch 流程等价） |
| `dbg_test.gdb` | 连接后 reset/load/break main/查看寄存器 |
| `inspect*.gdb` | 读取 UART2 寄存器、DMA 通道、`dma_resource_pools`、引脚 FUNC_CTL 等 |

> 注意：`inspect*.gdb` 中的寄存器地址/符号对应 HPM5301 + 本工程，改动后需同步。

## jlink/ — J-Link 命令行测试片段

用法：`JLink.exe -NoGui 1 -ExitOnError 1 -CommanderScript script_test\jlink\<script>.jlink`

| 文件 | 用途 |
| --- | --- |
| `jl_probe.jlink` | `ShowEmuList`，列出已连接的 J-Link |
| `jl_min.jlink` | 最小 JTAG 连接测试 |
| `jl_test3.jlink` | JTAG 自动探测 + 连接 + 读内存 |
| `jl_read.jlink` | 读 flash（APP 签名 `HPM!`） |
| `jl_pins.jlink` | 读 PA08/PA09/PB13 的 IOC FUNC_CTL 与 GPIO 输出状态 |
| `jl_load.jlink` | `erase` + `loadfile` 示例（路径需按需修改） |
| `jl_flashinfo.jlink` / `jl_help.jlink` / `jl_test.jlink` / `jl_test2.jlink` | 早期调试片段 |

## CDC + SWD 同时满载

SWD 压测（`swd/run_benchmark.py`，目标可为 STM32F1，`adapter speed` 20/36/45/60MHz）
与 CDC 连续流回环（`uart_stress_stream.py COM75 9000000 <秒>`）同时运行。

实测（SWD 1000 轮 + CDC 9Mbps 连续流）：

| SWD 速度 | CDC 速率 | SWD 校验 | CDC 连续流 |
| --- | --- | --- | --- |
| 20 MHz | 9 Mbps | 1000/1000 PASS | 8/8 OK（每轮 ~7MB） |
| 20 MHz | 10 Mbps | 1000/1000 PASS | 8/8 OK |
| 20 MHz | 22.5 Mbps | 1000/1000 PASS | 16/16 OK（2 轮，~230MB） |
| 36 MHz | 9 Mbps | 1000/1000 PASS | 全 OK |
| 45 MHz | 9 Mbps | 1000/1000 PASS | 全 OK |
| 60 MHz | 9 Mbps | 1000/1000 PASS | 全 OK |
| 60 MHz | 22.5 Mbps | 1000/1000 PASS | 4/4 OK |

说明：SWD 20MHz 的临界区抖动最大；即使 `20MHz SWD + 22.5Mbps CDC`（双向极限）
两轮 16/16 也全部干净，无掉/重数据。偶发失败需先排查硬件接触。

结论：SWD 20~60MHz 与 CDC 9Mbps **同时满载无掉数据/无重复**。
（关键修复：给 `g_uartrx` 的 DMA-TC 生产者补齐临界区；并用 GPTMR 定时器驱动 RX flush，
不依赖 IDLE/满缓冲中断。）

RX flush 定时器周期**按波特率动态调整**（目标每次约 512 字节，clamp 到 200us~10ms）：
低波特率时降低中断频率。实测 GPTMR RLD：`9600 → 10ms`、`9M → 568us`。

## 关键结论（回归基线）

- 回环压力测试：115200 / 460800 / 921600 / 1M / 2Mbps **全部通过**。
- 常见速率（`uart_loopback_common.py`）：9600~9M **全部通过**；
  6M→5.625M、8M→7.5M、10M→9M、11.25M→9M（9M 软件上限 + 就近取整）；高速线速效率 ~99.7%。
- 高速回环（1MB×多次，稳定）：2M~9M **全部通过**，线速效率 ~100%。
- 模式切换：空闲回环 OK → JTAG 下 COM 无回显（正常）→ SWD 恢复 OK → Disconnect 恢复 OK。
- 引脚状态：PB13 `FUNC_CTL=0` 且输出高（5V_EN 开）；空闲/SWD 下 PA08/PA09 `FUNC_CTL=2`(UART2)。
- RX 采用 **DMAV2 infinite-loop 圆形缓冲**（无 disable/restart），消除了重启边界上的重复字节。

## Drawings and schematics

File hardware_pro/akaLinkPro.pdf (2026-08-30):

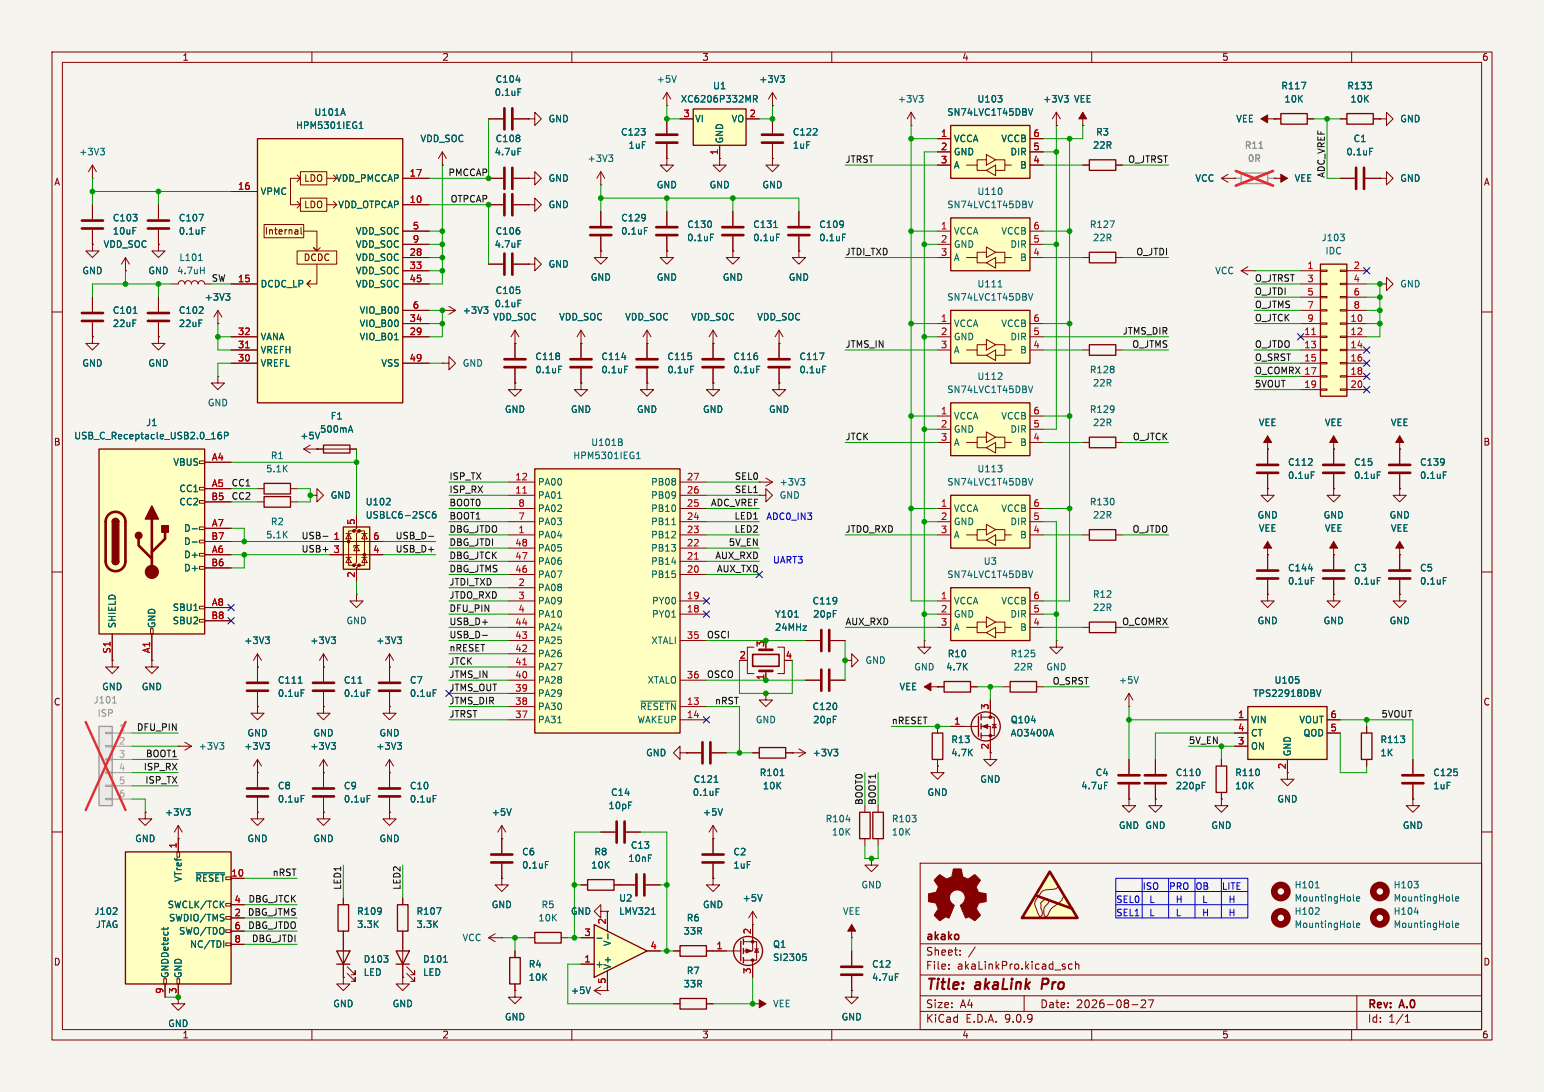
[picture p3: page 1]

3 ~{RESET}10 SWCLK/TCK 4 SWDIO/TMS 2 SWO/TDO 6 NC/TDI 8 C8

File: akaLinkPro.kicad_sch Sheet: / akako C8

3 ~{RESET}10 SWCLK/TCK 4 SWDIO/TMS 2 SWO/TDO 6 NC/TDI 8

Id: 1/1 Title: akaLink Pro

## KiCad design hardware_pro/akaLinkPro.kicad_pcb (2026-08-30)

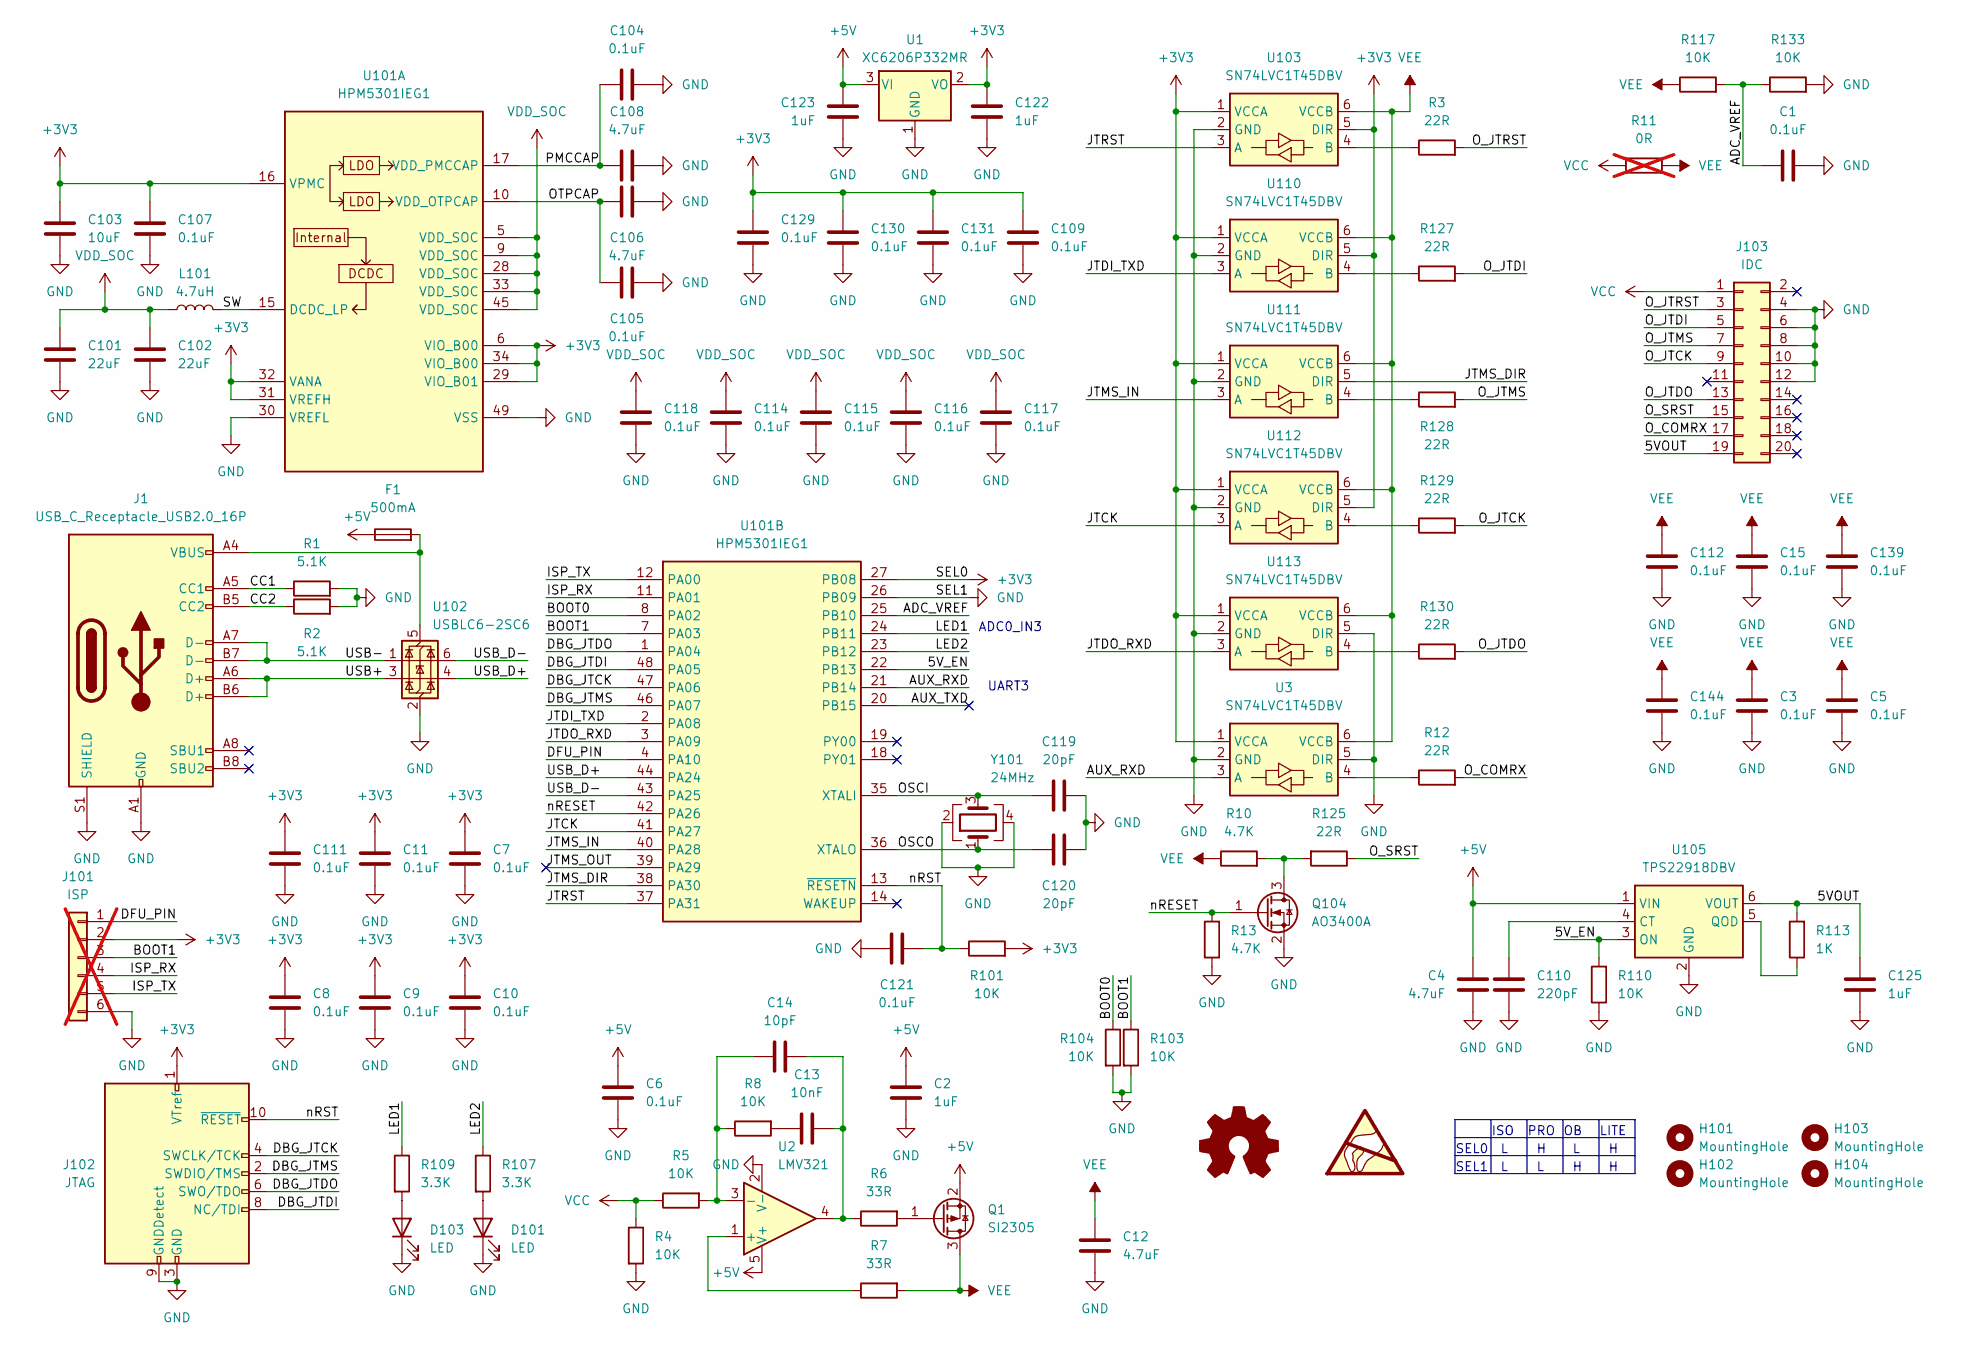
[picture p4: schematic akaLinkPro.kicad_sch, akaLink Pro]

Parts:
C1, C3, C5, C6, C7, C8, C9, C10, C11, C15, C104, C105, C107, C109, C111, C112, C114, C115, C116, C117, C118, C121, C129, C130, C131, C139, C144: 0.1uF; C_0603_1608Metric
C2, C122, C123, C125: 1uF; C_0603_1608Metric
C4, C12, C106, C108: 4.7uF; C_0603_1608Metric
C13: 10nF; C_0603_1608Metric
C14: 10pF; C_0603_1608Metric
C101, C102: 22uF; C_0805_2012Metric
C103: 10uF; C_0805_2012Metric
C110: 220pF; C_0603_1608Metric
C119, C120: 20pF; C_0603_1608Metric
D101, D103: LED; LED_D3.0mm_Clear
F1: 500mA; Fuse_0603_1608Metric
H101, H102, H103, H104: MountingHole; MountingHole_2.5mm
J1: USB_C_Receptacle_USB2.0_16P; USB_C_Receptacle_HRO_TYPE-C-31-M-12
J101: ISP; PinHeader_1x06_P2.54mm_Vertical; not fitted
J102: JTAG; PinHeader_2x05_P1.27mm_Vertical
J103: IDC; IDC-Header_2x10_P2.54mm_Horizontal
L101: 4.7uH; L_Sunlord_SWPA3012S
Q1: SI2305; SOT-23-3
Q104: AO3400A; SOT-23-3
R1, R2: 5.1K; R_0603_1608Metric
R3, R12, R125, R127, R128, R129, R130: 22R; R_0603_1608Metric
R4, R5, R8, R101, R103, R104, R110, R117, R133: 10K; R_0603_1608Metric
R6, R7: 33R; R_0603_1608Metric
R10, R13: 4.7K; R_0603_1608Metric
R11: 0R; R_0603_1608Metric; not fitted
R107, R109: 3.3K; R_0603_1608Metric
R113: 1K; R_0603_1608Metric
U1: XC6206P332MR; SOT-23-3
U2: LMV321; SOT-23-5
U3, U103, U110, U111, U112, U113: SN74LVC1T45DBV; SOT-23-6
U101: HPM5301IEG1; QFN-48-1EP_6x6mm_P0.4mm_EP4.2x4.2mm
U102: USBLC6-2SC6; SOT-23-6
U105: TPS22918DBV; SOT-23-6
Y101: 24MHz; Crystal_SMD_3225-4Pin_3.2x2.5mm

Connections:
+3V3: C7.1, C8.1, C9.1, C10.1, C11.1, C103.1, C107.1, C109.1, C111.1, C122.1, C129.1, C130.1, C131.1, J101.2, J102.1 (VTref), R101.2, U1.2 (VO), U3.1 (VCCA), U101.6 (VIO_B00), U101.16 (VPMC), U101.27 (PB08), U101.29 (VIO_B01), U101.31 (VREFH), U101.32 (VANA), U101.34 (VIO_B00), U103.1 (VCCA), U103.5 (DIR), U110.1 (VCCA), U110.5 (DIR), U111.1 (VCCA), U112.1 (VCCA), U112.5 (DIR), U113.1 (VCCA)
+5V: C2.1, C4.1, C6.1, C123.1, F1.1, Q1.2 (S), U1.3 (VI), U2.5 (V+), U105.1 (VIN)
/5VOUT: C125.1, J103.19, R113.2, U105.6 (VOUT)
/5V_EN: R110.2, U101.22 (PB13), U105.3 (ON)
/ADC_VREF: C1.1, R117.2, R133.1, U101.25 (PB10)
/AUX_RXD: U3.3 (A), U101.21 (PB14)
/AUX_TXD: U101.20 (PB15)
/BOOT0: R104.1, U101.8 (PA02)
/BOOT1: J101.3, R103.1, U101.7 (PA03)
/CC1: J1.A5 (CC1), R1.1
/CC2: J1.B5 (CC2), R2.1
/DBG_JTCK: J102.4 (SWCLK/TCK), U101.47 (PA06)
/DBG_JTDI: J102.8 (NC/TDI), U101.48 (PA05)
/DBG_JTDO: J102.6 (SWO/TDO), U101.1 (PA04)
/DBG_JTMS: J102.2 (SWDIO/TMS), U101.46 (PA07)
/DFU_PIN: J101.1, U101.4 (PA10)
/ISP_RX: J101.4, U101.11 (PA01)
/ISP_TX: J101.5, U101.12 (PA00)
/JTCK: U101.41 (PA27), U112.3 (A)
/JTDI_TXD: U101.2 (PA08), U110.3 (A)
/JTDO_RXD: U101.3 (PA09), U113.3 (A)
/JTMS_DIR: U101.38 (PA30), U111.5 (DIR)
/JTMS_IN: U101.40 (PA28), U111.3 (A)
/JTMS_OUT: U101.39 (PA29)
/JTRST: U101.37 (PA31), U103.3 (A)
/LED1: R109.1, U101.24 (PB11)
/LED2: R107.1, U101.23 (PB12)
/OSCI: C119.1, U101.35 (XTALI), Y101.3
/OSCO: C120.1, U101.36 (XTALO), Y101.1
/OTPCAP: C105.1, C106.1, U101.10 (VDD_OTPCAP)
/O_COMRX: J103.17, R12.2
/O_JTCK: J103.9, R129.2
/O_JTDI: J103.5, R127.2
/O_JTDO: J103.13, R130.2
/O_JTMS: J103.7, R128.2
/O_JTRST: J103.3, R3.2
/O_SRST: J103.15, R125.1
/PMCCAP: C104.1, C108.1, U101.17 (VDD_PMCCAP)
/SW: L101.2, U101.15 (DCDC_LP)
/USB+: J1.A6 (D+), J1.B6 (D+), U102.3 (I/O2)
/USB-: J1.A7 (D-), J1.B7 (D-), U102.1 (I/O1)
/USB_D+: U101.44 (PA24), U102.4 (I/O2)
/USB_D-: U101.43 (PA25), U102.6 (I/O1)
/nRESET: Q104.1 (G), R13.2, U101.42 (PA26)
/nRST: C121.1, J102.10 (~RESET), R101.1, U101.13 (~RESETN)
GND: C1.2, C2.2, C3.2, C4.2, C5.2, C6.2, C7.2, C8.2, C9.2, C10.2, C11.2, C12.2, C15.2, C101.2, C102.2, C103.2, C104.2, C105.2, C106.2, C107.2, C108.2, C109.2, C110.2, C111.2, C112.2, C114.2, C115.2, C116.2, C117.2, C118.2, C119.2, C120.2, C121.2, C122.2, C123.2, C125.2, C129.2, C130.2, C131.2, C139.2, C144.2, D101.1 (K), D103.1 (K), J1.A1 (GND), J1.A12 (GND), J1.B1 (GND), J1.B12 (GND), J1.S1 (SHIELD), J101.6, J102.3 (GND), J102.5 (GND), J102.9 (GNDDetect), J103.4, J103.6, J103.8, J103.10, J103.12, Q104.2 (S), R1.2, R2.2, R4.2, R13.1, R103.2, R104.2, R110.1, R133.2, U1.1 (GND), U2.2 (V-), U3.2 (GND), U3.5 (DIR), U101.26 (PB09), U101.30 (VREFL), U101.49 (VSS), U102.2 (GND), U103.2 (GND), U105.2 (GND), U110.2 (GND), U111.2 (GND), U112.2 (GND), U113.2 (GND), U113.5 (DIR), Y101.2, Y101.4
unnamed: C13.1, R8.2
unnamed: C13.2, C14.2, R6.1, U2.4
unnamed: D101.2 (A), R107.2
unnamed: D103.2 (A), R109.2
unnamed: Q1.1 (G), R6.2
unnamed: Q104.3 (D), R10.2, R125.2
unnamed: R7.1, U2.1 (+)
unnamed: C14.1, R5.2, R8.1, U2.3 (-)
unnamed: R12.1, U3.4 (B)
unnamed: F1.2, J1.A4 (VBUS), J1.A9 (VBUS), J1.B4 (VBUS), J1.B9 (VBUS), U102.5 (VBUS)
unnamed: R3.1, U103.4 (B)
unnamed: C110.1, U105.4 (CT)
unnamed: R113.1, U105.5 (QOD)
unnamed: R127.1, U110.4 (B)
unnamed: R128.1, U111.4 (B)
unnamed: R129.1, U112.4 (B)
unnamed: R130.1, U113.4 (B)
VCC: J103.1, R4.1, R5.1, R11.2
VDD_SOC: C101.1, C102.1, C114.1, C115.1, C116.1, C117.1, C118.1, L101.1, U101.5 (VDD_SOC), U101.9 (VDD_SOC), U101.28 (VDD_SOC), U101.33 (VDD_SOC), U101.45 (VDD_SOC)
VEE: C3.1, C5.1, C12.1, C15.1, C112.1, C139.1, C144.1, Q1.3 (D), R7.2, R10.1, R11.1, R117.1, U3.6 (VCCB), U103.6 (VCCB), U110.6 (VCCB), U111.6 (VCCB), U112.6 (VCCB), U113.6 (VCCB)

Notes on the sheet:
ISO
ADC0_IN3
PRO
SEL1
SEL0
UART3
LITE

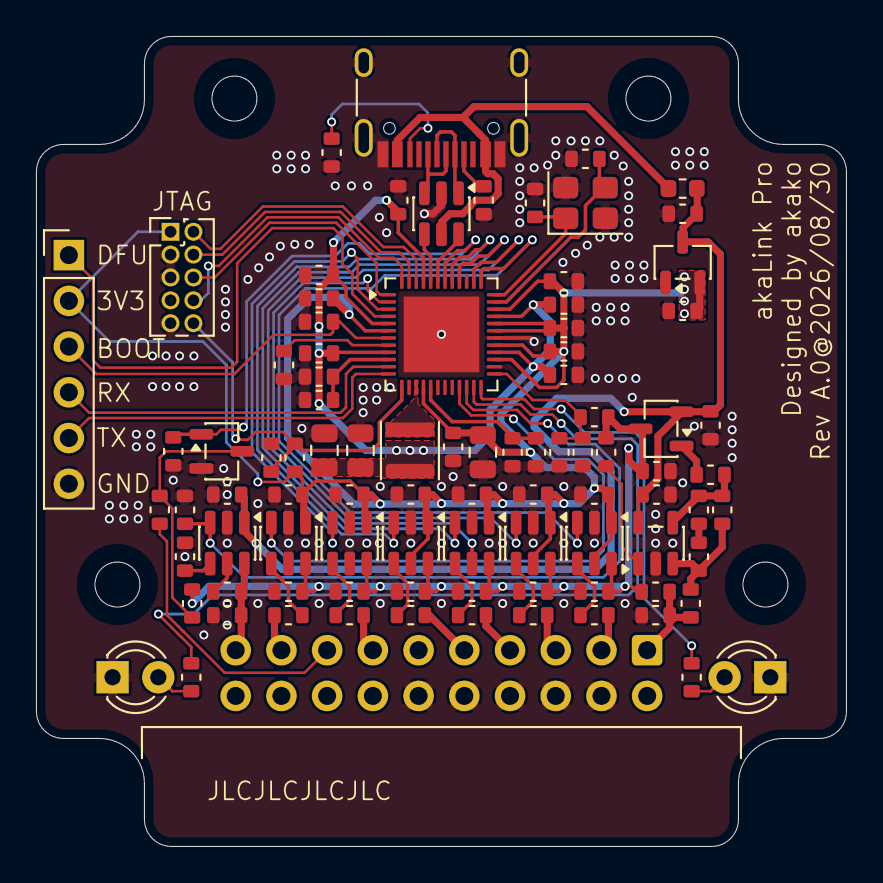
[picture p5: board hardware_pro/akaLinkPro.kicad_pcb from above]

Board: 2 copper layers, 45.0 x 45.0 mm, 95 parts (0 on the bottom side), 64 nets.

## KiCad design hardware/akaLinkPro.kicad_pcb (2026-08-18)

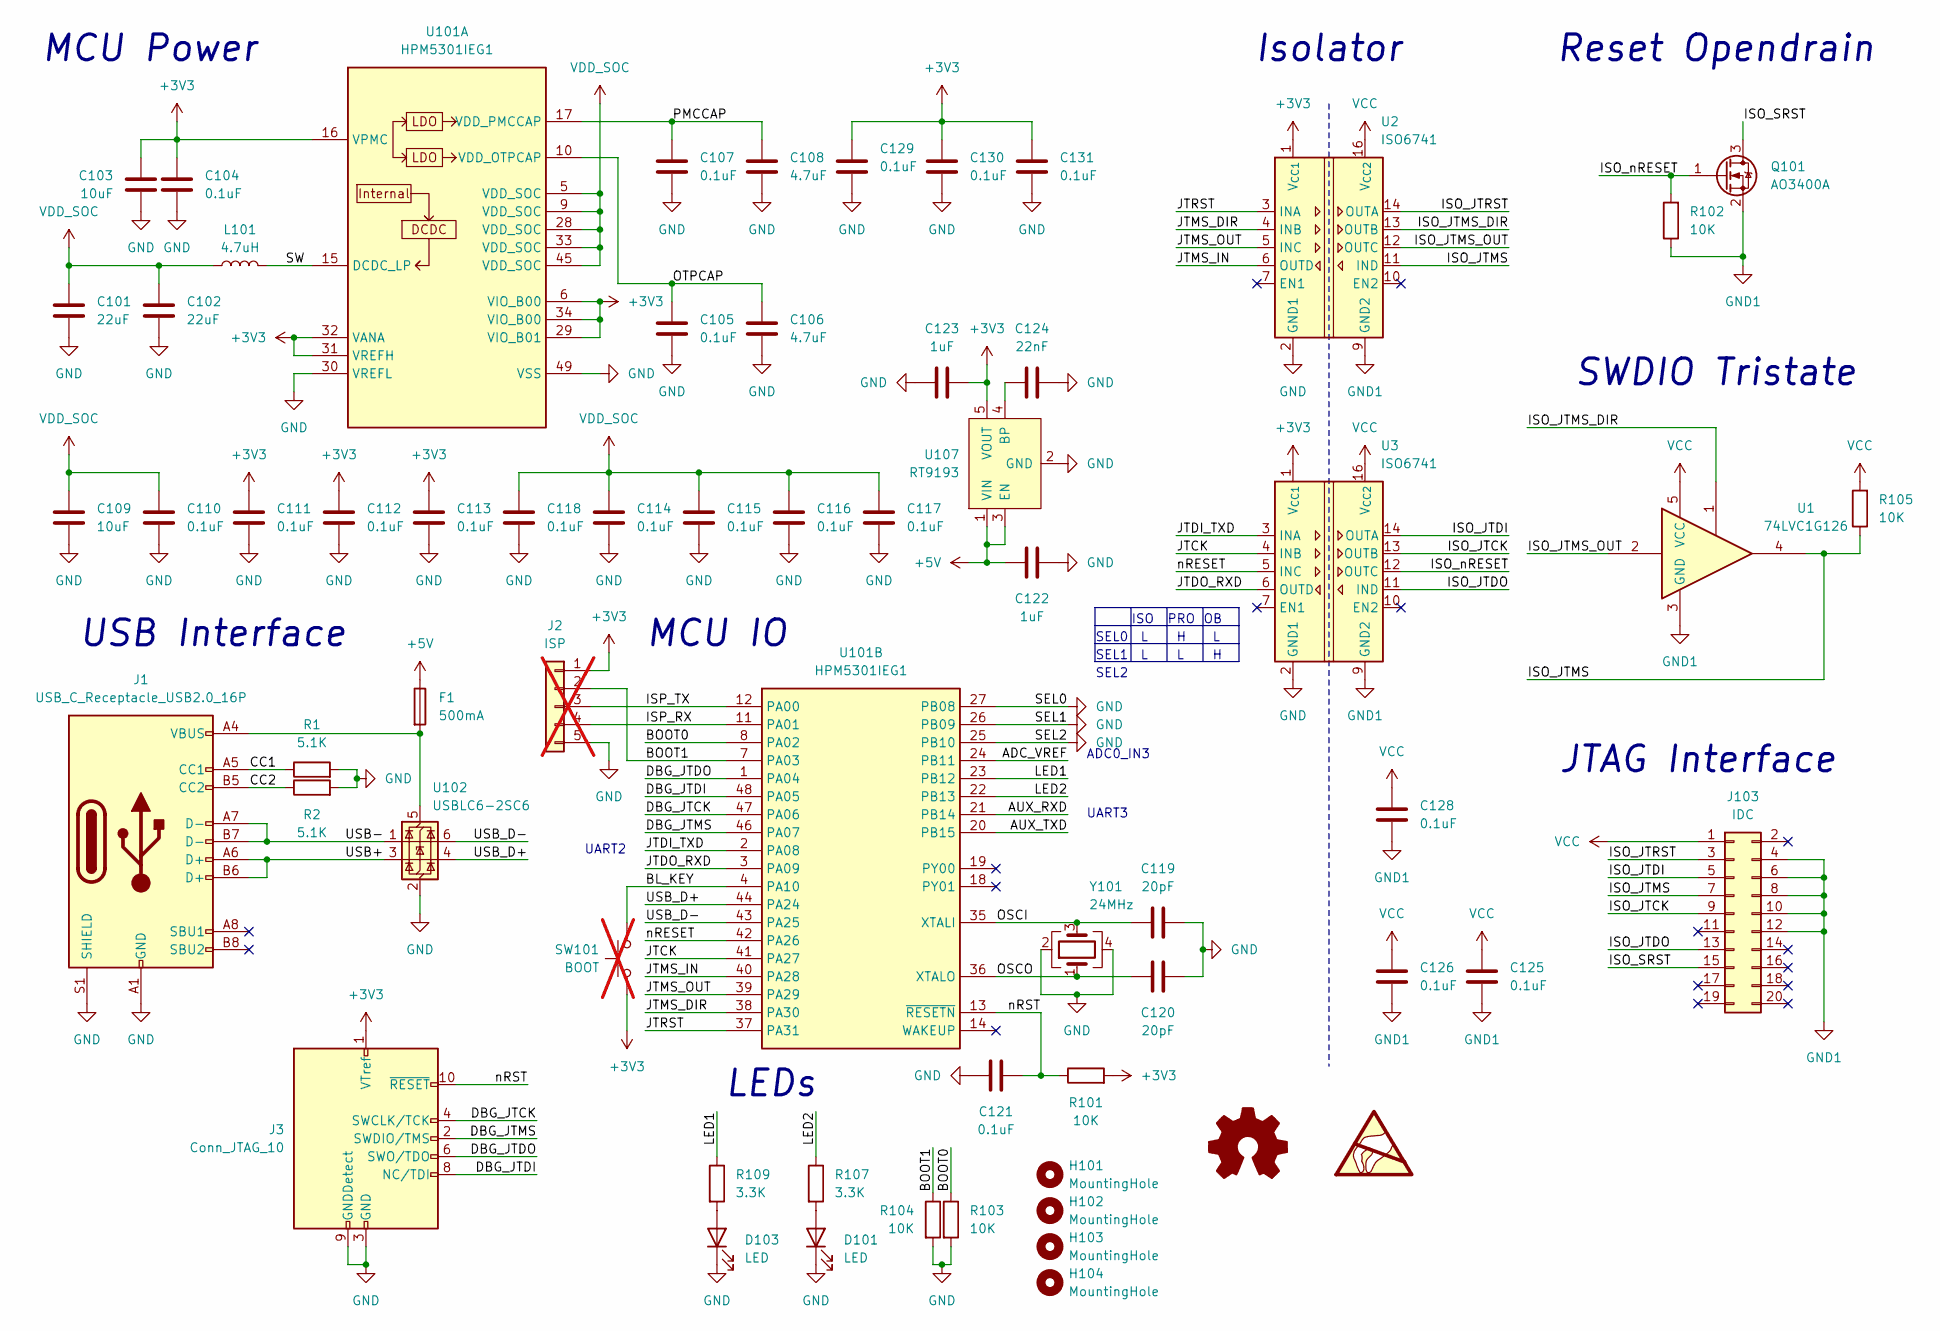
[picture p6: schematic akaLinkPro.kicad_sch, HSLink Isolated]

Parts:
C101, C102: 22uF; C_0805_2012Metric
C103, C109: 10uF; C_0805_2012Metric
C104, C105, C107, C110, C111, C112, C113, C114, C115, C116, C117, C118, C121, C125, C126, C128, C129, C130, C131: 0.1uF; C_0603_1608Metric
C106, C108: 4.7uF; C_0603_1608Metric
C119, C120: 20pF; C_0603_1608Metric
C122, C123: 1uF; C_0603_1608Metric
C124: 22nF; C_0603_1608Metric
D101, D103: LED; LED_0603_1608Metric
F1: 500mA; Fuse_0805_2012Metric
H101, H102, H103, H104: MountingHole; MountingHole_2.5mm
J1: USB_C_Receptacle_USB2.0_16P; USB_C_Receptacle_HRO_TYPE-C-31-M-12
J2: ISP; PinHeader_1x05_P2.54mm_Vertical; not fitted
J3: Conn_JTAG_10; PinHeader_2x05_P1.27mm_Vertical
J103: IDC; IDC-Header_2x10_P2.54mm_Horizontal
L101: 4.7uH; L_Sunlord_SWPA252012S
Q101: AO3400A; SOT-23
R1, R2: 5.1K; R_0603_1608Metric
R101, R102, R103, R104, R105: 10K; R_0603_1608Metric
R107, R109: 3.3K; R_0603_1608Metric
SW101: BOOT; PinHeader_1x02_P2.54mm_Vertical; not fitted
U1: 74LVC1G126; SOT-23-5
U2, U3: ISO6741; SOIC-16W_7.5x10.3mm_P1.27mm
U101: HPM5301IEG1; QFN-48-1EP_6x6mm_P0.4mm_EP4.2x4.2mm
U102: USBLC6-2SC6; SOT-23-6
U107: RT9193; SOT-23-5
Y101: 24MHz; Crystal_SMD_3225-4Pin_3.2x2.5mm

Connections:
+3V3: C103.1, C104.1, C111.1, C112.1, C113.1, C123.1, C129.1, C130.1, C131.1, J2.1, J3.1 (VTref), R101.2, SW101.2, U2.1 (V_{CC1}), U3.1 (V_{CC1}), U101.6 (VIO_B00), U101.16 (VPMC), U101.29 (VIO_B01), U101.31 (VREFH), U101.32 (VANA), U101.34 (VIO_B00), U107.5 (VOUT)
+5V: C122.1, F1.1, U107.1 (VIN), U107.3 (EN)
/ADC_VREF: U101.24 (PB11)
/AUX_RXD: U101.21 (PB14)
/AUX_TXD: U101.20 (PB15)
/BL_KEY: SW101.1, U101.4 (PA10)
/BOOT0: R103.1, U101.8 (PA02)
/BOOT1: J2.2, R104.1, U101.7 (PA03)
/CC1: J1.A5 (CC1), R1.1
/CC2: J1.B5 (CC2), R2.1
/DBG_JTCK: J3.4 (SWCLK/TCK), U101.47 (PA06)
/DBG_JTDI: J3.8 (NC/TDI), U101.48 (PA05)
/DBG_JTDO: J3.6 (SWO/TDO), U101.1 (PA04)
/DBG_JTMS: J3.2 (SWDIO/TMS), U101.46 (PA07)
/ISO_JTCK: J103.9, U3.13 (OUTB)
/ISO_JTDI: J103.5, U3.14 (OUTA)
/ISO_JTDO: J103.13, U3.11 (IND)
/ISO_JTMS: J103.7, R105.1, U1.4, U2.11 (IND)
/ISO_JTMS_DIR: U1.1, U2.13 (OUTB)
/ISO_JTMS_OUT: U1.2, U2.12 (OUTC)
/ISO_JTRST: J103.3, U2.14 (OUTA)
/ISO_SRST: J103.15, Q101.3 (D)
/ISO_nRESET: Q101.1 (G), R102.2, U3.12 (OUTC)
/ISP_RX: J2.4, U101.11 (PA01)
/ISP_TX: J2.3, U101.12 (PA00)
/JTCK: U3.4 (INB), U101.41 (PA27)
/JTDI_TXD: U3.3 (INA), U101.2 (PA08)
/JTDO_RXD: U3.6 (OUTD), U101.3 (PA09)
/JTMS_DIR: U2.4 (INB), U101.38 (PA30)
/JTMS_IN: U2.6 (OUTD), U101.40 (PA28)
/JTMS_OUT: U2.5 (INC), U101.39 (PA29)
/JTRST: U2.3 (INA), U101.37 (PA31)
/LED1: R109.1, U101.23 (PB12)
/LED2: R107.1, U101.22 (PB13)
/OSCI: C119.1, U101.35 (XTALI), Y101.3
/OSCO: C120.1, U101.36 (XTALO), Y101.1
/OTPCAP: C105.1, C106.1, U101.10 (VDD_OTPCAP)
/PMCCAP: C107.1, C108.1, U101.17 (VDD_PMCCAP)
/SW: L101.2, U101.15 (DCDC_LP)
/USB+: J1.A6 (D+), J1.B6 (D+), U102.3 (I/O2)
/USB-: J1.A7 (D-), J1.B7 (D-), U102.1 (I/O1)
/USB_D+: U101.44 (PA24), U102.4 (I/O2)
/USB_D-: U101.43 (PA25), U102.6 (I/O1)
/nRESET: U3.5 (INC), U101.42 (PA26)
/nRST: C121.1, J3.10 (~RESET), R101.1, U101.13 (~RESETN)
GND: C101.2, C102.2, C103.2, C104.2, C105.2, C106.2, C107.2, C108.2, C109.2, C110.2, C111.2, C112.2, C113.2, C114.2, C115.2, C116.2, C117.2, C118.2, C119.2, C120.2, C121.2, C122.2, C123.2, C124.2, C129.2, C130.2, C131.2, D101.1 (K), D103.1 (K), J1.A1 (GND), J1.A12 (GND), J1.B1 (GND), J1.B12 (GND), J1.S1 (SHIELD), J2.5, J3.3 (GND), J3.5 (GND), J3.9 (GNDDetect), R1.2, R2.2, R103.2, R104.2, U2.2 (GND1), U2.8 (GND1), U3.2 (GND1), U3.8 (GND1), U101.25 (PB10), U101.26 (PB09), U101.27 (PB08), U101.30 (VREFL), U101.49 (VSS), U102.2 (GND), U107.2 (GND), Y101.2, Y101.4
GND1: C125.2, C126.2, C128.2, J103.4, J103.6, J103.8, J103.10, J103.12, Q101.2 (S), R102.1, U1.3 (GND), U2.9 (GND2), U2.15 (GND2), U3.9 (GND2), U3.15 (GND2)
unnamed: D101.2 (A), R107.2
unnamed: D103.2 (A), R109.2
unnamed: F1.2, J1.A4 (VBUS), J1.A9 (VBUS), J1.B4 (VBUS), J1.B9 (VBUS), U102.5 (VBUS)
unnamed: C124.1, U107.4 (BP)
VCC: C125.1, C126.1, C128.1, J103.1, R105.2, U1.5 (VCC), U2.16 (V_{CC2}), U3.16 (V_{CC2})
VDD_SOC: C101.1, C102.1, C109.1, C110.1, C114.1, C115.1, C116.1, C117.1, C118.1, L101.1, U101.5 (VDD_SOC), U101.9 (VDD_SOC), U101.28 (VDD_SOC), U101.33 (VDD_SOC), U101.45 (VDD_SOC)

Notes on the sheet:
ISO
ADC0_IN3
PRO
JTAG Interface
UART2
Isolator
USB Interface
SEL1
SEL0
Reset Opendrain
MCU Power
UART3
MCU IO
SWDIO Tristate
LEDs
SEL2

Board: 2 copper layers, 60 parts (0 on the bottom side), 50 nets, no tracks yet.

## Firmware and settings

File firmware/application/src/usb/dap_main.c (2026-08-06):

#include "dap_main.h"
#include "hpm_dfu_trigger.h"
#include "hpm_otp_drv.h"

#define CMSIS_DAP_INTERFACE_SIZE (9 + 7 + 7)
#define CUSTOM_HID_LEN (9 + 9 + 7 + 7)
#define DFU_RUNTIME_INTERFACE_SIZE (9 + 9)

#define HIDRAW_INTERVAL 10

#define HID_CUSTOM_REPORT_DESC_SIZE 53

#define USBD_WINUSB_VENDOR_CODE 0x20
#define USBD_WEBUSB_VENDOR_CODE 0x21

#define USBD_WEBUSB_ENABLE 1
#define USBD_BULK_ENABLE 1
#define USBD_WINUSB_ENABLE 1
#define USBD_DFU_RUNTIME_ENABLE 1

/* WinUSB Microsoft OS 2.0 descriptor sizes */
#define WINUSB_DESCRIPTOR_SET_HEADER_SIZE 10
#define WINUSB_FUNCTION_SUBSET_HEADER_SIZE 8
#define WINUSB_FEATURE_COMPATIBLE_ID_SIZE 20

#define FUNCTION_SUBSET_LEN 160
#define DEVICE_INTERFACE_GUIDS_FEATURE_LEN 132

#define USBD_WINUSB_DESC_SET_LEN (WINUSB_DESCRIPTOR_SET_HEADER_SIZE +        \
                                  USBD_WEBUSB_ENABLE * FUNCTION_SUBSET_LEN + \
                                  USBD_BULK_ENABLE * FUNCTION_SUBSET_LEN +   \
                                  USBD_DFU_RUNTIME_ENABLE * FUNCTION_SUBSET_LEN)

#define USBD_NUM_DEV_CAPABILITIES (USBD_WEBUSB_ENABLE + USBD_WINUSB_ENABLE)

#define USBD_WEBUSB_DESC_LEN 24
#define USBD_WINUSB_DESC_LEN 28

#define USBD_BOS_WTOTALLENGTH (0x05 +                                      \
                               USBD_WEBUSB_DESC_LEN * USBD_WEBUSB_ENABLE + \
                               USBD_WINUSB_DESC_LEN * USBD_WINUSB_ENABLE)

#define USB_CONFIG_SIZE (9 +                                                    \
                         CMSIS_DAP_INTERFACE_SIZE + CDC_ACM_DESCRIPTOR_LEN +    \
                         CONFIG_CHERRYDAP_USE_CUSTOM_HID * CUSTOM_HID_LEN +     \
                         USBD_WEBUSB_ENABLE * 9 +                               \
                         USBD_DFU_RUNTIME_ENABLE * DFU_RUNTIME_INTERFACE_SIZE + \
                         CONFIG_CHERRYDAP_USE_MSC * MSC_DESCRIPTOR_LEN)

#define INTF_NUM (1 + 2 + CONFIG_CHERRYDAP_USE_CUSTOM_HID + USBD_WEBUSB_ENABLE + USBD_DFU_RUNTIME_ENABLE + CONFIG_CHERRYDAP_USE_MSC)

#define MSC_INTF_NUM (3 + CONFIG_CHERRYDAP_USE_CUSTOM_HID)
#define WEBUSB_INTF_NUM (MSC_INTF_NUM + CONFIG_CHERRYDAP_USE_MSC)
#define DFU_INTF_NUM (WEBUSB_INTF_NUM + 1)

#define DFU_INTF_STRING_INDEX 0x05
#define WEB_INTF_STRING_INDEX 0x04
#define MSC_INTF_STRING_INDEX 0x06

#define WEBUSB_URL_STRINGS \
    'c', 'h', 'e', 'r', 'r', 'y', 'd', 'a', 'p', '.', 'c', 'h', 'e', 'r', 'r', 'y', '-', 'e', 'm', 'b', 'e', 'd', 'd', 'e', 'd', '.', 'o', 'r', 'g',

__ALIGN_BEGIN const uint8_t USBD_WinUSBDescriptorSetDescriptor[] = {
    WBVAL(WINUSB_DESCRIPTOR_SET_HEADER_SIZE), /* wLength */
    WBVAL(WINUSB_SET_HEADER_DESCRIPTOR_TYPE), /* wDescriptorType */
    0x00, 0x00, 0x03, 0x06, /* >= Win 8.1 */  /* dwWindowsVersion*/
    WBVAL(USBD_WINUSB_DESC_SET_LEN),          /* wDescriptorSetTotalLength */
#if (USBD_WEBUSB_ENABLE)
    WBVAL(WINUSB_FUNCTION_SUBSET_HEADER_SIZE), // wLength
    WBVAL(WINUSB_SUBSET_HEADER_FUNCTION_TYPE), // wDescriptorType
    WEBUSB_INTF_NUM,                           // bFirstInterface USBD_WINUSB_IF_NUM
    0,                                         // bReserved
    WBVAL(FUNCTION_SUBSET_LEN),                // wSubsetLength
    WBVAL(WINUSB_FEATURE_COMPATIBLE_ID_SIZE),  // wLength
    WBVAL(WINUSB_FEATURE_COMPATIBLE_ID_TYPE),  // wDescriptorType
    'W', 'I', 'N', 'U', 'S', 'B', 0, 0,        // CompatibleId
    0, 0, 0, 0, 0, 0, 0, 0,                    // SubCompatibleId
    WBVAL(DEVICE_INTERFACE_GUIDS_FEATURE_LEN), // wLength
    WBVAL(WINUSB_FEATURE_REG_PROPERTY_TYPE),   // wDescriptorType
    WBVAL(WINUSB_PROP_DATA_TYPE_REG_MULTI_SZ), // wPropertyDataType
    WBVAL(42),                                 // wPropertyNameLength
    'D', 0, 'e', 0, 'v', 0, 'i', 0, 'c', 0, 'e', 0,
    'I', 0, 'n', 0, 't', 0, 'e', 0, 'r', 0, 'f', 0, 'a', 0, 'c', 0, 'e', 0,
    'G', 0, 'U', 0, 'I', 0, 'D', 0, 's', 0, 0, 0,
    WBVAL(80), // wPropertyDataLength
    '{', 0,
    '9', 0, '2', 0, 'C', 0, 'E', 0, '6', 0, '4', 0, '6', 0, '2', 0, '-', 0,
    '9', 0, 'C', 0, '7', 0, '7', 0, '-', 0,
    '4', 0, '6', 0, 'F', 0, 'E', 0, '-', 0,
    '9', 0, '3', 0, '3', 0, 'B', 0, '-',
    0, '3', 0, '1', 0, 'C', 0, 'B', 0, '9', 0, 'C', 0, '5', 0, 'A', 0, 'A', 0, '3', 0, 'B', 0, '9', 0,
    '}', 0, 0, 0, 0, 0,
#endif
#if USBD_BULK_ENABLE
    WBVAL(WINUSB_FUNCTION_SUBSET_HEADER_SIZE), /* wLength */
    WBVAL(WINUSB_SUBSET_HEADER_FUNCTION_TYPE), /* wDescriptorType */
    0,                                         /* bFirstInterface USBD_BULK_IF_NUM*/
    0,                                         /* bReserved */
    WBVAL(FUNCTION_SUBSET_LEN),                /* wSubsetLength */
    WBVAL(WINUSB_FEATURE_COMPATIBLE_ID_SIZE),  /* wLength */
    WBVAL(WINUSB_FEATURE_COMPATIBLE_ID_TYPE),  /* wDescriptorType */
    'W', 'I', 'N', 'U', 'S', 'B', 0, 0,        /* CompatibleId*/
    0, 0, 0, 0, 0, 0, 0, 0,                    /* SubCompatibleId*/
    WBVAL(DEVICE_INTERFACE_GUIDS_FEATURE_LEN), /* wLength */
    WBVAL(WINUSB_FEATURE_REG_PROPERTY_TYPE),   /* wDescriptorType */
    WBVAL(WINUSB_PROP_DATA_TYPE_REG_MULTI_SZ), /* wPropertyDataType */
    WBVAL(42),                                 /* wPropertyNameLength */
    'D', 0, 'e', 0, 'v', 0, 'i', 0, 'c', 0, 'e', 0,
    'I', 0, 'n', 0, 't', 0, 'e', 0, 'r', 0, 'f', 0, 'a', 0, 'c', 0, 'e', 0,
    'G', 0, 'U', 0, 'I', 0, 'D', 0, 's', 0, 0, 0,
    WBVAL(80), /* wPropertyDataLength */
    '{', 0,
    'C', 0, 'D', 0, 'B', 0, '3', 0, 'B', 0, '5', 0, 'A', 0, 'D', 0, '-', 0,
    '2', 0, '9', 0, '3', 0, 'B', 0, '-', 0,
    '4', 0, '6', 0, '6', 0, '3', 0, '-', 0,
    'A', 0, 'A', 0, '3', 0, '6', 0, '-',
    0, '1', 0, 'A', 0, 'A', 0, 'E', 0, '4', 0, '6', 0, '4', 0, '6', 0, '3', 0, '7', 0, '7', 0, '6', 0,
    '}', 0, 0, 0, 0, 0,
#endif
#if USBD_DFU_RUNTIME_ENABLE
    /* WinUSB function subset for the DFU runtime interface so that Windows
     * binds WinUSB to it and libusb (dfu-util) can claim the interface. */
    WBVAL(WINUSB_FUNCTION_SUBSET_HEADER_SIZE), /* wLength */
    WBVAL(WINUSB_SUBSET_HEADER_FUNCTION_TYPE), /* wDescriptorType */
    DFU_INTF_NUM,                              /* bFirstInterface */
    0,                                         /* bReserved */
    WBVAL(FUNCTION_SUBSET_LEN),                /* wSubsetLength */
    WBVAL(WINUSB_FEATURE_COMPATIBLE_ID_SIZE),  /* wLength */
    WBVAL(WINUSB_FEATURE_COMPATIBLE_ID_TYPE),  /* wDescriptorType */
    'W', 'I', 'N', 'U', 'S', 'B', 0, 0,        /* CompatibleId*/
    0, 0, 0, 0, 0, 0, 0, 0,                    /* SubCompatibleId*/
    WBVAL(DEVICE_INTERFACE_GUIDS_FEATURE_LEN), /* wLength */
    WBVAL(WINUSB_FEATURE_REG_PROPERTY_TYPE),   /* wDescriptorType */
    WBVAL(WINUSB_PROP_DATA_TYPE_REG_MULTI_SZ), /* wPropertyDataType */
    WBVAL(42),                                 /* wPropertyNameLength */
    'D', 0, 'e', 0, 'v', 0, 'i', 0, 'c', 0, 'e', 0,
    'I', 0, 'n', 0, 't', 0, 'e', 0, 'r', 0, 'f', 0, 'a', 0, 'c', 0, 'e', 0,
    'G', 0, 'U', 0, 'I', 0, 'D', 0, 's', 0, 0, 0,
    WBVAL(80), /* wPropertyDataLength */
    '{', 0,
    '8', 0, 'F', 0, '3', 0, 'A', 0, '6', 0, 'C', 0, '1', 0, 'D', 0, '-', 0,
    '4', 0, 'B', 0, '2', 0, '7', 0, '-', 0,
    '4', 0, 'E', 0, '9', 0, 'A', 0, '-', 0,
    'A', 0, 'C', 0, '1', 0, '5', 0, '-',
    0, '7', 0, 'D', 0, '2', 0, 'E', 0, '0', 0, 'B', 0, '6', 0, '9', 0, 'F', 0, '5', 0, 'C', 0, '3', 0,
    '}', 0, 0, 0, 0, 0
#endif
};

__ALIGN_BEGIN const uint8_t USBD_BinaryObjectStoreDescriptor[] = {
    0x05,                         /* bLength */
    0x0f,                         /* bDescriptorType */
    WBVAL(USBD_BOS_WTOTALLENGTH), /* wTotalLength */
    USBD_NUM_DEV_CAPABILITIES,    /* bNumDeviceCaps */
#if (USBD_WEBUSB_ENABLE)
    USBD_WEBUSB_DESC_LEN,           /* bLength */
    0x10,                           /* bDescriptorType */
    USB_DEVICE_CAPABILITY_PLATFORM, /* bDevCapabilityType */
    0x00,                           /* bReserved */
    0x38,
    0xB6,
    0x08,
    0x34, /* PlatformCapabilityUUID */
    0xA9,
    0x09,
    0xA0,
    0x47,
    0x8B,
    0xFD,
    0xA0,
    0x76,
    0x88,
    0x15,
    0xB6,
    0x65,
    WBVAL(0x0100),
    /* 1.00 */               /* bcdVersion */
    USBD_WEBUSB_VENDOR_CODE, /* bVendorCode */
    1,                       /* iLandingPage */
#endif
#if (USBD_WINUSB_ENABLE)
    USBD_WINUSB_DESC_LEN,           /* bLength */
    0x10,                           /* bDescriptorType */
    USB_DEVICE_CAPABILITY_PLATFORM, /* bDevCapabilityType */
    0x00,                           /* bReserved */
    0xDF,
    0x60,
    0xDD,
    0xD8, /* PlatformCapabilityUUID */
    0x89,
    0x45,
    0xC7,
    0x4C,
    0x9C,
    0xD2,
    0x65,
    0x9D,
    0x9E,
    0x64,
    0x8A,
    0x9F,
    0x00,
    0x00,
    0x03,
    0x06,
    /* >= Win 8.1 */                 /* dwWindowsVersion*/
    WBVAL(USBD_WINUSB_DESC_SET_LEN), /* wDescriptorSetTotalLength */
    USBD_WINUSB_VENDOR_CODE,         /* bVendorCode */
    0,                               /* bAltEnumCode */
#endif
};

#define URL_DESCRIPTOR_LENGTH (3 + 29)

const uint8_t USBD_WebUSBURLDescriptor[URL_DESCRIPTOR_LENGTH] = {
    URL_DESCRIPTOR_LENGTH,
    WEBUSB_URL_TYPE,
    WEBUSB_URL_SCHEME_HTTPS,
    WEBUSB_URL_STRINGS};

// clang-format off
#define HID_DESC()                                                                                                                       \
    /************** Descriptor of Custom interface *****************/                                                                    \
    0x09,                                               /* bLength: Interface Descriptor size */                                         \
    USB_DESCRIPTOR_TYPE_INTERFACE,                  /* bDescriptorType: Interface descriptor type */                                 \
    0X03,                                           /* bInterfaceNumber: Number of Interface */                                      \
    0x00,                                           /* bAlternateSetting: Alternate setting */                                       \
    0x02,                                           /* bNumEndpoints */                                                              \
    0x03,                                           /* bInterfaceClass: HID */                                                       \
    0x01,                                           /* bInterfaceSubClass : 1=BOOT, 0=no boot */                                     \
    0x00,                                           /* nInterfaceProtocol : 0=none, 1=keyboard, 2=mouse */                           \
    0, /* iInterface: Index of string descriptor */ /******************** Descriptor of Custom HID ********************/             \
    0x09,                                           /* bLength: HID Descriptor size */                                               \
    HID_DESCRIPTOR_TYPE_HID,                        /* bDescriptorType: HID */                                                       \
    0x11,                                           /* bcdHID: HID Class Spec release number */                                      \
    0x01,                                                                                                                            \
    0x00,                                              /* bCountryCode: Hardware target country */                                   \
    0x01,                                              /* bNumDescriptors: Number of HID class descriptors to follow */              \
    0x22,                                              /* bDescriptorType */                                                         \
    HID_CUSTOM_REPORT_DESC_SIZE,                       /* wItemLength: Total length of Report descriptor */                          \
    0x00,                                              /******************** Descriptor of Custom in endpoint ********************/  \
    0x07,                                              /* bLength: Endpoint Descriptor size */                                       \
    USB_DESCRIPTOR_TYPE_ENDPOINT,                      /* bDescriptorType: */                                                        \
    HID_IN_EP,                                         /* bEndpointAddress: Endpoint Address (IN) */                                 \
    0x03,                                              /* bmAttributes: Interrupt endpoint */                                        \
    WBVAL(HID_PACKET_SIZE),                            /* wMaxPacketSize: 4 Byte max */                                              \
    HIDRAW_INTERVAL, /* bInterval: Polling Interval */ /******************** Descriptor of Custom out endpoint ********************/ \
    0x07,                                              /* bLength: Endpoint Descriptor size */                                       \
    USB_DESCRIPTOR_TYPE_ENDPOINT,                      /* bDescriptorType: */                                                        \
    HID_OUT_EP,                                        /* bEndpointAddress: Endpoint Address (IN) */                                 \
    0x03,                                              /* bmAttributes: Interrupt endpoint */                                        \
    WBVAL(HID_PACKET_SIZE),                            /* wMaxPacketSize: 4 Byte max */                                              \
    HIDRAW_INTERVAL                                    /* bInterval: Polling Interval */
// clang-format on

static const uint8_t device_descriptor[] = {
    /* bcdDevice bumped 0x0100 -> 0x0102: Windows includes REV_xxxx (bcdDevice)
     * in the hardware ID, so changing it forces a brand-new device instance and
     * a fresh MS OS 2.0 descriptor fetch. Needed so Windows picks up the new
     * WinUSB function subset for the DFU runtime interface (intf 5) instead of
     * reusing the cached descriptor set that only covered intf 0 and 4. */
    USB_DEVICE_DESCRIPTOR_INIT(USB_2_1, 0xEF, 0x02, 0x01, USBD_VID, USBD_PID, 0x0100, 0x01),
};

static const uint8_t config_descriptor[] = {
    USB_CONFIG_DESCRIPTOR_INIT(USB_CONFIG_SIZE, INTF_NUM, 0x01, USB_CONFIG_BUS_POWERED, USBD_MAX_POWER),
    /* Interface 0 */
    USB_INTERFACE_DESCRIPTOR_INIT(0x00, 0x00, 0x02, 0xFF, 0x00, 0x00, 0x02),
    /* Endpoint OUT 2 */
    USB_ENDPOINT_DESCRIPTOR_INIT(DAP_OUT_EP, USB_ENDPOINT_TYPE_BULK, DAP_PACKET_SIZE, 0x00),
    /* Endpoint IN 1 */
    USB_ENDPOINT_DESCRIPTOR_INIT(DAP_IN_EP, USB_ENDPOINT_TYPE_BULK, DAP_PACKET_SIZE, 0x00),
    CDC_ACM_DESCRIPTOR_INIT(0x01, CDC_INT_EP, CDC_OUT_EP, CDC_IN_EP, DAP_PACKET_SIZE, 0x00),
#if CONFIG_CHERRYDAP_USE_CUSTOM_HID
    HID_DESC(),
#endif
#if CONFIG_CHERRYDAP_USE_MSC
    MSC_DESCRIPTOR_INIT(MSC_INTF_NUM, MSC_OUT_EP, MSC_IN_EP, DAP_PACKET_SIZE, MSC_INTF_STRING_INDEX),
#endif
#if USBD_WEBUSB_ENABLE
    USB_INTERFACE_DESCRIPTOR_INIT(WEBUSB_INTF_NUM, 0x00, 0x00, 0xff, 0x00, 0x00, WEB_INTF_STRING_INDEX),
#endif
#if USBD_DFU_RUNTIME_ENABLE
    /* DFU runtime interface (no endpoints, uses EP0 only) */
    USB_INTERFACE_DESCRIPTOR_INIT(DFU_INTF_NUM, 0x00, 0x00, 0xFE, 0x01, 0x01, DFU_INTF_STRING_INDEX),
    /* DFU Functional Descriptor */
    0x09,
    0x21, /* bLength, bDescriptorType = DFU_FUNCTIONAL */
    0x0B, /* bmAttributes: bitCanDnload|bitCanUpload|bitWillDetach */
    0xFF,
    0x00, /* wDetachTimeOut = 255ms */
    0x00,
    0x10, /* wTransferSize = 4096 */
    0x1A,
    0x01, /* bcdDFU = 1.1a */
#endif
};

static const uint8_t other_speed_config_descriptor[] = {
    USB_CONFIG_DESCRIPTOR_INIT(USB_CONFIG_SIZE, INTF_NUM, 0x01, USB_CONFIG_BUS_POWERED, USBD_MAX_POWER),
    /* Interface 0 */
    USB_INTERFACE_DESCRIPTOR_INIT(0x00, 0x00, 0x02, 0xFF, 0x00, 0x00, 0x02),
    /* Endpoint OUT 2 */
    USB_ENDPOINT_DESCRIPTOR_INIT(DAP_OUT_EP, USB_ENDPOINT_TYPE_BULK, DAP_PACKET_SIZE, 0x00),
    /* Endpoint IN 1 */
    USB_ENDPOINT_DESCRIPTOR_INIT(DAP_IN_EP, USB_ENDPOINT_TYPE_BULK, DAP_PACKET_SIZE, 0x00),
    CDC_ACM_DESCRIPTOR_INIT(0x01, CDC_INT_EP, CDC_OUT_EP, CDC_IN_EP, DAP_PACKET_SIZE, 0x00),
#if CONFIG_CHERRYDAP_USE_CUSTOM_HID
    HID_DESC(),
#endif
#if CONFIG_CHERRYDAP_USE_MSC
    MSC_DESCRIPTOR_INIT(0x04, MSC_OUT_EP, MSC_IN_EP, DAP_PACKET_SIZE, MSC_INTF_STRING_INDEX),
#endif
#if USBD_WEBUSB_ENABLE
    USB_INTERFACE_DESCRIPTOR_INIT(WEBUSB_INTF_NUM, 0x00, 0x00, 0xff, 0x00, 0x00, WEB_INTF_STRING_INDEX),
#endif
#if USBD_DFU_RUNTIME_ENABLE
    /* DFU runtime interface (no endpoints, uses EP0 only) */
    USB_INTERFACE_DESCRIPTOR_INIT(DFU_INTF_NUM, 0x00, 0x00, 0xFE, 0x01, 0x01, DFU_INTF_STRING_INDEX),
    /* DFU Functional Descriptor */
    0x09,
    0x21, /* bLength, bDescriptorType = DFU_FUNCTIONAL */
    0x0B, /* bmAttributes: bitCanDnload|bitCanUpload|bitWillDetach */
    0xFF,
    0x00, /* wDetachTimeOut = 255ms */
    0x00,
    0x10, /* wTransferSize = 4096 */
    0x1A,
    0x01, /* bcdDFU = 1.1a */
#endif
};

/*!< custom hid report descriptor */
const uint8_t hid_custom_report_desc[HID_CUSTOM_REPORT_DESC_SIZE] = {
    /* USER CODE BEGIN 0 */
    0x06, 0x00, 0xff, /* USAGE_PAGE (Vendor Defined Page 1) */
    0x09, 0x01,       /* USAGE (Vendor Usage 1) */
    0xa1, 0x01,       /* COLLECTION (Application) */
    0x85, 0x02,       /*   REPORT ID (0x02) */
    0x09, 0x02,       /*   USAGE (Vendor Usage 1) */
    0x15, 0x00,       /*   LOGICAL_MINIMUM (0) */
    0x25, 0xff,       /*LOGICAL_MAXIMUM (255) */
    0x75, 0x08,       /*   REPORT_SIZE (8) */
    0x96, 0x3f, 0x00, /*   REPORT_COUNT (63) */
    0x81, 0x02,       /*   INPUT (Data,Var,Abs) */
    /* <___________________________________________________> */
    0x85, 0x01,       /*   REPORT ID (0x01) */
    0x09, 0x03,       /*   USAGE (Vendor Usage 1) */
    0x15, 0x00,       /*   LOGICAL_MINIMUM (0) */
    0x25, 0xff,       /*   LOGICAL_MAXIMUM (255) */
    0x75, 0x08,       /*   REPORT_SIZE (8) */
    0x96, 0x3f, 0x00, /*   REPORT_COUNT (63) */
    0x91, 0x02,       /*   OUTPUT (Data,Var,Abs) */

    /* <___________________________________________________> */
    0x85, 0x03,       /*   REPORT ID (0x03) */
    0x09, 0x04,       /*   USAGE (Vendor Usage 1) */
    0x15, 0x00,       /*   LOGICAL_MINIMUM (0) */
    0x25, 0xff,       /*   LOGICAL_MAXIMUM (255) */
    0x75, 0x08,       /*   REPORT_SIZE (8) */
    0x96, 0x3f, 0x00, /*   REPORT_COUNT (63) */
    0xb1, 0x02,       /*   FEATURE (Data,Var,Abs) */
    /* USER CODE END 0 */
    0xC0 /*     END_COLLECTION	             */
};

char serial_number_dynamic[33] = {0}; // Dynamic serial number

char *string_descriptors[] = {
    (char[]){0x09, 0x04},   /* Langid */
    "ARM",                  /* Manufacturer */
    "akaLinkPro CMSIS-DAP", /* Product */
    "Serial Number",        /* Serial Number */
    "akaLinkPro WebUSB",
    "akaLinkPro DFU Runtime",
    "akaLinkPro MSC Disk"};

static const uint8_t device_quality_descriptor[] = {
    USB_DEVICE_QUALIFIER_DESCRIPTOR_INIT(USB_2_1, 0x00, 0x00, 0x00, 0x01),
};

__WEAK const uint8_t *device_descriptor_callback(uint8_t speed)
{
    (void)speed;
    return device_descriptor;
}

__WEAK const uint8_t *config_descriptor_callback(uint8_t speed)
{
    (void)speed;
    return config_descriptor;
}

__WEAK const uint8_t *device_quality_descriptor_callback(uint8_t speed)
{
    (void)speed;
    return device_quality_descriptor;
}

__WEAK const uint8_t *other_speed_config_descriptor_callback(uint8_t speed)
{
    (void)speed;
    return other_speed_config_descriptor;
}

__WEAK const char *string_descriptor_callback(uint8_t speed, uint8_t index)
{
    (void)speed;

    if (index == 3)
    {
        return serial_number_dynamic;
    }

    if (index >= (sizeof(string_descriptors) / sizeof(char *)))
    {
        return NULL;
    }
    return string_descriptors[index];
}

// static volatile uint16_t USB_RequestIndexI = 0; // Request  Index In
// static volatile uint16_t USB_RequestIndexO = 0; // Request  Index Out
// static volatile uint16_t USB_RequestCountI = 0; // Request  Count In
// static volatile uint16_t USB_RequestCountO = 0; // Request  Count Out
// static volatile uint8_t USB_RequestIdle = 1;    // Request  Idle  Flag

// static volatile uint16_t USB_ResponseIndexI = 0; // Response Index In
// static volatile uint16_t USB_ResponseIndexO = 0; // Response Index Out
// static volatile uint16_t USB_ResponseCountI = 0; // Response Count In
// static volatile uint16_t USB_ResponseCountO = 0; // Response Count Out
// static volatile uint8_t USB_ResponseIdle = 1;    // Response Idle  Flag

// static USB_NOCACHE_RAM_SECTION USB_MEM_ALIGNX uint8_t USB_Request[DAP_PACKET_COUNT][DAP_PACKET_SIZE];  // Request  Buffer
// static USB_NOCACHE_RAM_SECTION USB_MEM_ALIGNX uint8_t USB_Response[DAP_PACKET_COUNT][DAP_PACKET_SIZE]; // Response Buffer
// static uint16_t USB_RespSize[DAP_PACKET_COUNT];                                                        // Response Size

// volatile struct cdc_line_coding g_cdc_lincoding;
// volatile uint8_t config_uart = 0;
// volatile uint8_t config_uart_transfer = 0;

// USB_NOCACHE_RAM_SECTION USB_MEM_ALIGNX uint8_t uartrx_ringbuffer[CONFIG_UARTRX_RINGBUF_SIZE];
// USB_NOCACHE_RAM_SECTION USB_MEM_ALIGNX uint8_t usbrx_ringbuffer[CONFIG_USBRX_RINGBUF_SIZE];
// USB_NOCACHE_RAM_SECTION USB_MEM_ALIGNX uint8_t usb_tmpbuffer[DAP_PACKET_SIZE];

// static volatile uint8_t usbrx_idle_flag = 0;
// static volatile uint8_t usbtx_idle_flag = 0;
// static volatile uint8_t uarttx_idle_flag = 0;

// USB_NOCACHE_RAM_SECTION chry_ringbuffer_t g_uartrx;
// USB_NOCACHE_RAM_SECTION chry_ringbuffer_t g_usbrx;
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

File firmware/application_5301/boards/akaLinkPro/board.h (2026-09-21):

/*
 * Copyright (c) 2023-2026 HPMicro
 *
 * SPDX-License-Identifier: BSD-3-Clause
 *
 */

#ifndef _HPM_BOARD_H
#define _HPM_BOARD_H
#include <stdio.h>
#include <stdarg.h>
#include "hpm_common.h"
#include "hpm_clock_drv.h"
#include "hpm_soc.h"
#include "hpm_soc_feature.h"
#include "pinmux.h"
#if !defined(CONFIG_NDEBUG_CONSOLE) || !CONFIG_NDEBUG_CONSOLE
#include "hpm_debug_console.h"
#endif

#define BOARD_NAME "akaLinkPro"
#define BOARD_UF2_SIGNATURE (0x0A4D5048UL)
#define BOARD_DFU_SIGNATURE (0x48504D21UL)
#define BOARD_BGPR HPM_BGPR0

/* core section */
#ifndef BOARD_RUNNING_CORE
#define BOARD_RUNNING_CORE HPM_CORE0
#endif

/* uart section */
#ifndef BOARD_APP_UART_BASE
#define BOARD_APP_UART_BASE HPM_UART3
#define BOARD_APP_UART_IRQ IRQn_UART3
#define BOARD_APP_UART_BAUDRATE (115200UL)
#define BOARD_APP_UART_CLK_NAME clock_uart3
#define BOARD_APP_UART_RX_DMA_REQ HPM_DMA_SRC_UART3_RX
#define BOARD_APP_UART_TX_DMA_REQ HPM_DMA_SRC_UART3_TX
#endif

#define BOARD_APP_UART_BREAK_SIGNAL_PIN IOC_PAD_PA26

#if !defined(CONFIG_NDEBUG_CONSOLE) || !CONFIG_NDEBUG_CONSOLE
#ifndef BOARD_CONSOLE_TYPE
#define BOARD_CONSOLE_TYPE CONSOLE_TYPE_UART
#endif

#if BOARD_CONSOLE_TYPE == CONSOLE_TYPE_UART
#ifndef BOARD_CONSOLE_UART_BASE
#define BOARD_CONSOLE_UART_BASE HPM_UART0
#define BOARD_CONSOLE_UART_CLK_NAME clock_uart0
#define BOARD_CONSOLE_UART_IRQ IRQn_UART0
#define BOARD_CONSOLE_UART_TX_DMA_REQ HPM_DMA_SRC_UART0_TX
#define BOARD_CONSOLE_UART_RX_DMA_REQ HPM_DMA_SRC_UART0_RX
#endif
#define BOARD_CONSOLE_UART_BAUDRATE (115200UL)
#endif
#endif

/* nor flash section */
#define BOARD_FLASH_BASE_ADDRESS (0x80000000UL) /* Check */
#define BOARD_FLASH_SIZE (SIZE_1MB)

/* XPI NOR configuration for ROM API (same as the DFU bootloader). */
#define BOARD_APP_XPI_NOR_XPI_BASE (HPM_XPI0)
#define BOARD_APP_XPI_NOR_CFG_OPT_HDR (0xfcf90002U)
#define BOARD_APP_XPI_NOR_CFG_OPT_OPT0 (0x00000006U)
#define BOARD_APP_XPI_NOR_CFG_OPT_OPT1 (0x00001000U)

/* Configuration store: the last two 4K sectors of the 1MB QSPI NOR
 * (0x800FE000 - 0x800FFFFF) are reserved for the APP-owned parameter store.
 * They sit at the tail of the APP region, never in the bootloader region. */
#define BOARD_PARAM_RESERVED_SIZE (0x2000UL)

/* gpiom section */
#define BOARD_APP_GPIOM_BASE HPM_GPIOM
#define BOARD_APP_GPIOM_USING_CTRL HPM_FGPIO
#define BOARD_APP_GPIOM_USING_CTRL_NAME gpiom_core0_fast

/* User button */
#define BOARD_APP_GPIO_CTRL HPM_GPIO0
#define BOARD_APP_GPIO_INDEX GPIO_DI_GPIOA
#define BOARD_APP_GPIO_PIN 3
#define BOARD_APP_GPIO_IRQ IRQn_GPIO0_A
#define BOARD_BUTTON_PRESSED_VALUE 1

#ifndef BOARD_SHOW_CLOCK
#define BOARD_SHOW_CLOCK 1
#endif
#ifndef BOARD_SHOW_BANNER
#define BOARD_SHOW_BANNER 1
#endif


#define BOARD_PIN_UART_TXD      IOC_PAD_PA08
#define BOARD_PIN_UART_RXD      IOC_PAD_PA09

#define BOARD_PIN_JTCK          IOC_PAD_PA27
#define BOARD_PIN_JTMS          IOC_PAD_PA28
// #define BOARD_PIN_JTMS_OUT      IOC_PAD_PA29
#define BOARD_PIN_JTMS_DIR      IOC_PAD_PA30
#define BOARD_PIN_JTDO          IOC_PAD_PA09
#define BOARD_PIN_JTDI          IOC_PAD_PA08
#define BOARD_PIN_JTRST         IOC_PAD_PA31
#define BOARD_PIN_nRESET        IOC_PAD_PA26


#define PIN_GPIOM_BASE    HPM_GPIOM
#define PIN_GPIO          HPM_FGPIO
#define PIN_GPIOM         gpiom_core0_fast


#if defined(__cplusplus)
extern "C"
{
#endif /* __cplusplus */

    typedef void (*board_timer_cb)(void);

    void board_init_gpio_pins(void);
    void board_init_usb(USB_Type *ptr);
    void board_init_console(void);
    void board_init_uart(UART_Type *ptr);

    void board_init(void);
    void board_init_usb_dp_dm_pins(void);
    void board_init_clock(void);
    void board_delay_us(uint32_t us);
    void board_delay_ms(uint32_t ms);
    void board_ungate_mchtmr_at_lp_mode(void);

    void board_init_pmp(void);
    uint32_t board_init_uart_clock(UART_Type *ptr);
    void init_uart_pins(UART_Type *ptr);
    void init_usb_pins(USB_Type *ptr);
#if defined(__cplusplus)
}
#endif /* __cplusplus */
#endif /* _HPM_BOARD_H */

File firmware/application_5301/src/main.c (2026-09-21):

/*
 * Copyright (c) 2021 HPMicro
 *
 * SPDX-License-Identifier: BSD-3-Clause
 *
 */

#include <stdio.h>
#include "board.h"
#include "hpm_debug_console.h"
#include "hpm_gpio_drv.h"
#include "hpm_soc.h"
#include "hpm_usb_drv.h"
#include "hpm_interrupt.h"
#include "usb_config.h"
#include "hpm_dfu_trigger.h"
#include "api_param.h"
#include "usb_composite.h"
#include "led_state.h"

int main(void)
{
    board_init();
    api_param_load();

    board_init_usb((USB_Type *)CONFIG_HPM_USBD_BASE);
    intc_set_irq_priority(CONFIG_HPM_USBD_IRQn, 2);
    chry_dap_init(0, CONFIG_HPM_USBD_BASE);

    /* Bring up the UART2 <-> CDC COM port bridge. DAP_SETUP() above parks
     * PA08/PA09 as GPIO, so this must run afterwards to mux them to UART2. */
    uartx_preinit();

    /* Status LEDs, external reference ADC and the periodic LED tick. */
    led_state_init();

    while (1)
    {
        chry_dap_handle();
        chry_dap_usb2uart_handle();
        api_param_poll();
    }
    return 0;
}

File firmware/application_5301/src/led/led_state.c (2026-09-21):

/* SPDX-License-Identifier: Apache-2.0 */
/* Copyright (c) 2026 akaInstruments */

#include "board.h"
#include "clock.h"
#include "hpm_gpio_drv.h"
#include "hpm_gptmr_drv.h"
#include "hpm_adc16_drv.h"
#include "hpm_interrupt.h"
#include "led_state.h"
#include "api_param.h"

/* LED pins (active high): LED1 blue = PB11, LED2 yellow = PB12. */
#define LED1_PIN IOC_PAD_PB11
#define LED2_PIN IOC_PAD_PB12

/* External reference is divided by two 10k resistors on PB10 (ADC0.2). */
#define LED_ADC_PIN IOC_PAD_PB10
#define LED_ADC_BASE HPM_ADC0
#define LED_ADC_CH (2U)
#define LED_ADC_FULL_SCALE_MV (3300U)
#define LED_ADC_SAMPLE_CYCLE (20U)

/* Dedicated timer tick; GPTMR0 is already used by the CDC flush timer. */
#define LED_TICK_TIMER HPM_GPTMR1
#define LED_TICK_TIMER_IRQ IRQn_GPTMR1
#define LED_TICK_TIMER_CH (0U)
#define LED_TICK_PERIOD_MS (50U)

/* 5Hz blink = 200ms period = 100ms on + 100ms off = 2 ticks per half. */
#define LED_BLINK_HALF_TICKS (2U)

#define LED_VREF_ON_PERCENT (90U)
#define LED_VREF_OFF_PERCENT (85U)

static volatile uint8_t s_dap_running;
static volatile uint8_t s_dap_connected;

/* Incremented by the USB/UART paths; the tick converts a change into a hold. */
static volatile uint32_t s_tx_activity;
static volatile uint32_t s_rx_activity;
static uint32_t s_tx_activity_seen;
static uint32_t s_rx_activity_seen;
static uint8_t s_tx_hold;
static uint8_t s_rx_hold;

static uint32_t s_tick;
static uint8_t s_vref_on;
static uint8_t s_adc_ready;
static volatile uint16_t s_external_mv;

static void led_write(uint16_t pin, uint8_t on)
{
    gpio_write_pin(HPM_GPIO0, GPIO_GET_PORT_INDEX(pin), GPIO_GET_PIN_INDEX(pin), on ? 1U : 0U);
}

void led_state_set_dap_running(uint8_t on)
{
    s_dap_running = on ? 1U : 0U;
}

void led_state_set_dap_connected(uint8_t on)
{
    s_dap_connected = on ? 1U : 0U;
}

void led_state_notify_uart_tx(uint32_t bytes)
{
    if (bytes)
    {
        s_tx_activity++;
    }
}

void led_state_notify_uart_rx(uint32_t bytes)
{
    if (bytes)
    {
        s_rx_activity++;
    }
}

uint16_t led_state_get_external_mv(void)
{
    return s_external_mv;
}

static void led_adc_init(void)
{
    adc16_config_t cfg;
    adc16_channel_config_t ch_cfg;

    init_adc0_bus_clock();

    adc16_get_default_config(&cfg);
    cfg.res = adc16_res_16_bits;
    cfg.conv_mode = adc16_conv_mode_oneshot;
    cfg.adc_clk_div = adc16_clock_divider_4;
#if !defined(HPM_IP_FEATURE_ADC16_FORCE_SYNC_AHB) || !HPM_IP_FEATURE_ADC16_FORCE_SYNC_AHB
    cfg.sel_sync_ahb = true;
#endif
    if (adc16_init(LED_ADC_BASE, &cfg) != status_success)
    {
        return;
    }

    adc16_get_channel_default_config(&ch_cfg);
    ch_cfg.ch = LED_ADC_CH;
    ch_cfg.sample_cycle = LED_ADC_SAMPLE_CYCLE;
    if (adc16_init_channel(LED_ADC_BASE, &ch_cfg) != status_success)
    {
        return;
    }

#if defined(ADC_SOC_BUSMODE_ENABLE_CTRL_SUPPORT) && ADC_SOC_BUSMODE_ENABLE_CTRL_SUPPORT
    adc16_enable_oneshot_mode(LED_ADC_BASE);
#endif

    s_adc_ready = 1U;
}

/* Sample the divided reference and update the mode-5 state with hysteresis:
 * on at 90% of the setting, off at 85%. */
static void led_vref_update(void)
{
    uint16_t raw;
    uint32_t ext_mv;
    uint32_t set_mv = g_param.vref_mv;
    uint32_t on_mv;
    uint32_t off_mv;

    if (!s_adc_ready)
    {
        return;
    }
    if (adc16_get_oneshot_result(LED_ADC_BASE, LED_ADC_CH, &raw) != status_success)
    {
        return;
    }

    /* result / 65535 * 3.3V, then x2 to undo the 10k/10k divider. */
    ext_mv = (uint32_t)raw * (LED_ADC_FULL_SCALE_MV * 2U) / 65535U;
    s_external_mv = (uint16_t)ext_mv;

    if (set_mv < 1800U)
    {
        set_mv = 1800U;
    }
    else if (set_mv > 5000U)
    {
        set_mv = 5000U;
    }
    on_mv = set_mv * LED_VREF_ON_PERCENT / 100U;
    off_mv = set_mv * LED_VREF_OFF_PERCENT / 100U;

    if (s_vref_on)
    {
        if (ext_mv < off_mv)
        {
            s_vref_on = 0U;
        }
    }
    else
    {
        if (ext_mv >= on_mv)
        {
            s_vref_on = 1U;
        }
    }
}

static uint8_t led_mode_eval(uint8_t mode, uint8_t blink_on, uint8_t tx_on, uint8_t rx_on)
{
    switch (mode)
    {
    case LED_MODE_DAP_RUNNING:
        return s_dap_running;
    case LED_MODE_DAP_CONNECT:
        return s_dap_connected;
    case LED_MODE_DAP_ANY:
        return (s_dap_running || s_dap_connected) ? blink_on : 1U;
    case LED_MODE_POWER:
        return 1U;
    case LED_MODE_VREF:
        return s_vref_on;
    case LED_MODE_CDC_TX:
        return tx_on;
    case LED_MODE_CDC_RX:
        return rx_on;
    case LED_MODE_CDC_TX_RX:
        return (tx_on || rx_on) ? 1U : 0U;
    case LED_MODE_OFF:
    default:
        return 0U;
    }
}
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

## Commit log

2026-08-06 sync boards with hpm5301evklite
2026-08-06 update pin define
2026-08-11 modify pin define
2026-08-15 add hardware and 80m swd
    [HSLinkIsolate.kicad_pcb, HSLinkIsolate.kicad_sch]
2026-08-17 update hardware
    [HSLinkIsolate.kicad_pcb, HSLinkIsolate.kicad_sch]
2026-08-18 add hardware
    [HSLinkIsolate.kicad_pcb, HSLinkIsolate.kicad_sch]
2026-08-18 update pcb
    [HSLinkIsolate.kicad_pcb, HSLinkIsolate.kicad_sch]
2026-08-18 update pcb name
    [akaLinkPro.kicad_pcb, akaLinkPro.kicad_sch]
2026-08-30 finish hardware
    [akaLinkPro.kicad_pcb, akaLinkPro.kicad_sch, bom.csv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]
2026-09-16 add swd speed switch function
2026-09-21 fix com port stress test
    [DAP_config.h, cdc_interface.c, uart_loopback_common.py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]
2026-09-21 clamp uart2 clock to 80mhz
2026-09-21 add led config
2026-11-01 增加Lite硬件
